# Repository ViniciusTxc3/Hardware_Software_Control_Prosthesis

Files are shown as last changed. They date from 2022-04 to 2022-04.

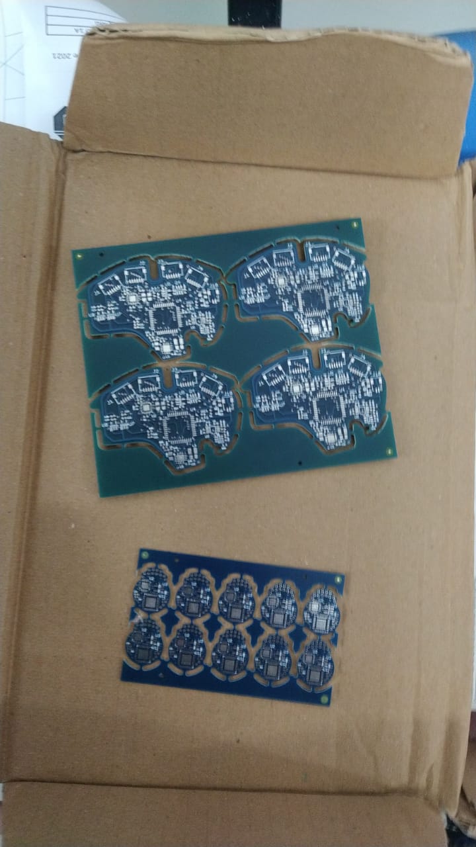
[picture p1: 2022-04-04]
img/placas_prontas.jpg

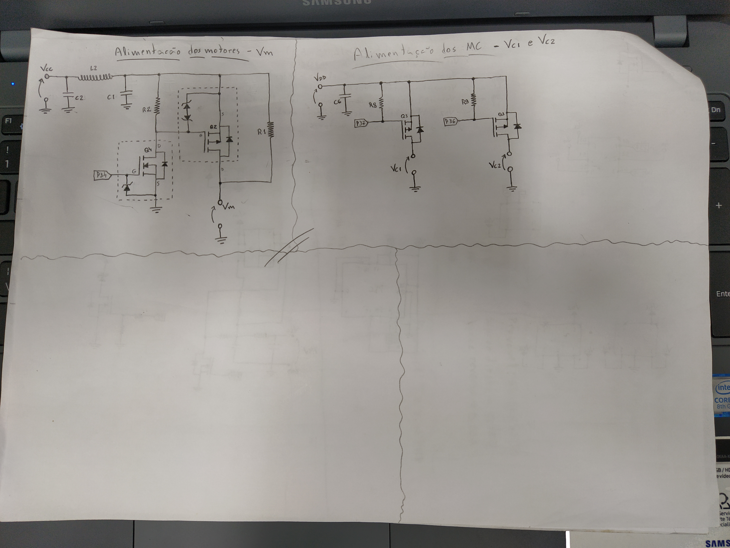
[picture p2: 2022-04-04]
img/rascunho/IMG_20200423_212037.jpg

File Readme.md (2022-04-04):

Trabalho desenvolvido no BioLab - UFU para o controle de uma prótese robótica. Nele consta o desenvolvimento do software de controle em um microcontrolador DSPIC em c/c++ e os design das placas de controle PCB.

# Esse trabalho teve a colaboração direta de:
* Vinicius Teixeira da Costa, 
* Professor Alcimar Barbosa Soares, 
* Eber Lawrence Gouveia, 
* Arthur Coeolho

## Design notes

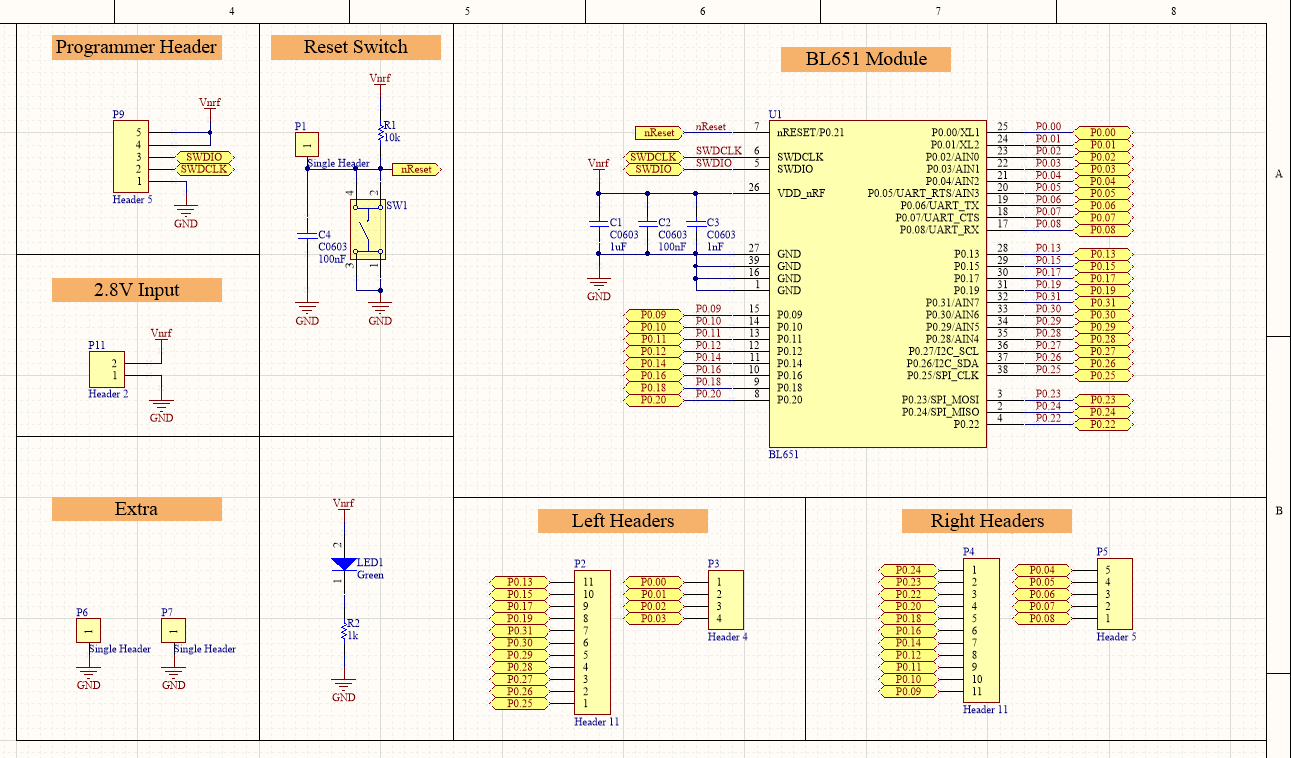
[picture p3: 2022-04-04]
datasheets/Bluetooth/Schematic_BL651.png

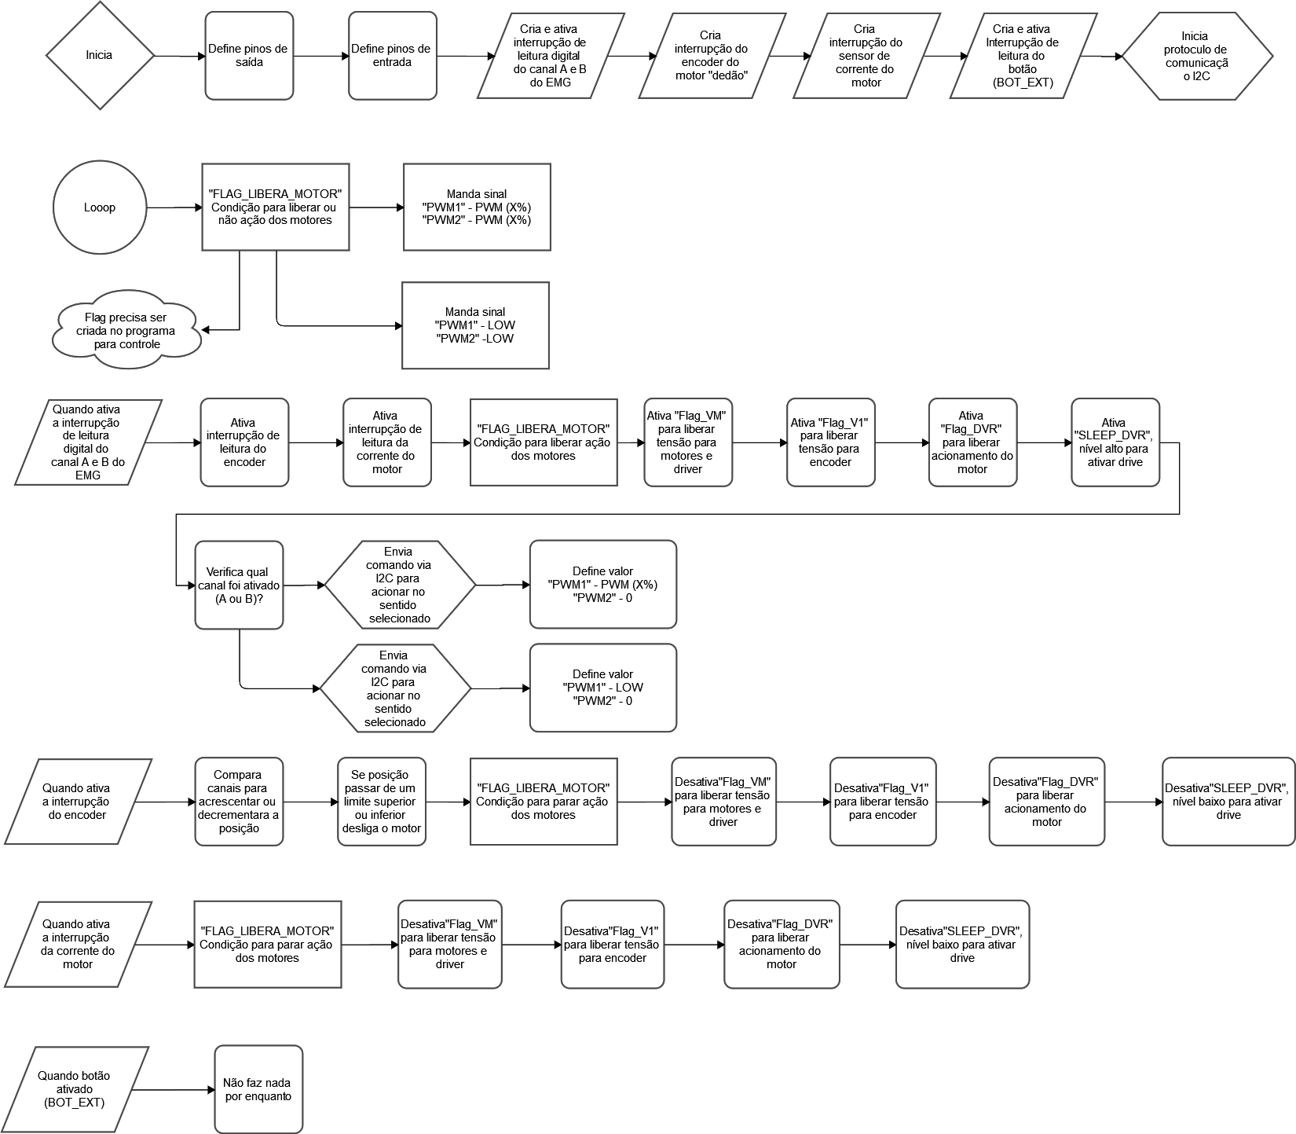
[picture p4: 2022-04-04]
Fluxograma_protese_grap_power.png

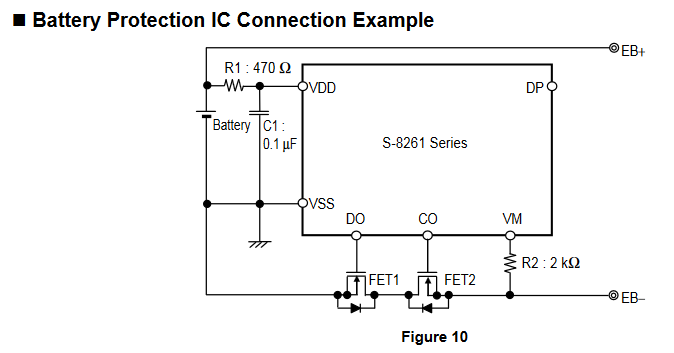
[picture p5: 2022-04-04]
datasheets/CIs/protection battery example.png

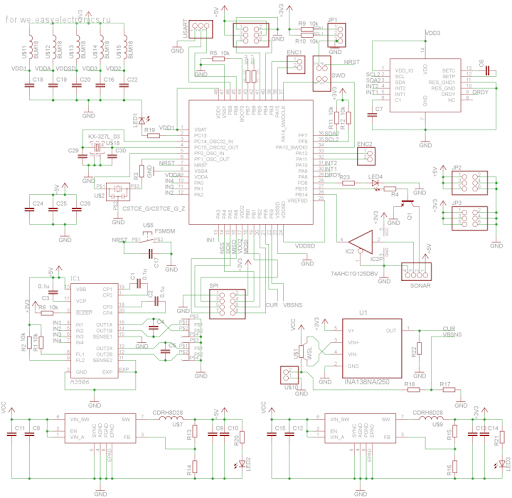
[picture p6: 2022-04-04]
datasheets/Driver potencia - A3906/example.png

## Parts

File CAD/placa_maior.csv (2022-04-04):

Qty | Value | Device | Package | Parts | Description | ALLIED_NUMBER | ALLIED_PRICE-STOCK | AVAILABILITY | DESCRIPTION | HEIGHT | MANUFACTURER_NAME | MANUFACTURER_PART_NUMBER | MF | MOUSER_PART_NUMBER | MOUSER_PRICE-STOCK | MP | MPN | OC_FARNELL | OC_NEWARK | PACKAGE | POPULARITY | PRICE | RS_PART_NUMBER | RS_PRICE-STOCK
1 | A3906SESTR-T | A3906 | QFN20 | U2 | Low Voltage Stepper and Single/Dual DC Motor Driver |  |  |  |  |  |  |  |  |  |  |  |  |  |  |  | 0
1 | 0.033R | R-US_R0805 | R0805 | R1 | RESISTOR, American symbol
13 | 0.1uF | C-EUC0402K | C0402K | C1, C2, C3, C4, C6, C8, C9, C11, C12, C14, C15, C21, C27 | CAPACITOR, European symbol
2 | 100K | R-US_R0402 | R0402 | R46, R58 | RESISTOR, American symbol
1 | 100R | R-US_R0402 | R0402 | R26 | RESISTOR, American symbol
2 | 10K | R-US_R0402 | R0402 | R42, R43 | RESISTOR, American symbol
13 | 10k | R-US_R0402 | R0402 | R6, R18, R27, R29, R30, R32, R33, R35, R44, R51, R54, R56, R57 | RESISTOR, American symbol
1 | 10pF | C-EUC0402K | C0402K | C5 | CAPACITOR, European symbol
1 | 10uF | C-EUC0402K | C0402K | C20 | CAPACITOR, European symbol
4 | 10uF | C-EUC0805K | C0805K | C7, C10, C16, C31 | CAPACITOR, European symbol
2 | 120R | R-US_R0402 | R0402 | R7, R15 | RESISTOR, American symbol
1 | 18k | R-US_R0402 | R0402 | R10 | RESISTOR, American symbol
1 | 190k | R-US_R0402 | R0402 | R5 | RESISTOR, American symbol
1 | 1M | R-US_R0402 | R0402 | R49 | RESISTOR, American symbol
3 | 1k | R-US_R0402 | R0402 | R3, R28, R37 | RESISTOR, American symbol
5 | 1uF | C-EUC0402K | C0402K | C13, C17, C25, C26, C32 | CAPACITOR, European symbol
2 | 2.2uF | C-EUC0402K | C0402K | C34, C35 | CAPACITOR, European symbol
1 | 22uF | C-EUC0805K | C0805K | C30 | CAPACITOR, European symbol
2 | 27k | R-US_R0402 | R0402 | R40, R41 | RESISTOR, American symbol
1 | 2k2 | R-US_R0402 | R0402 | R50 | RESISTOR, American symbol
1 | 39k | R-US_R0402 | R0402 | R55 | RESISTOR, American symbol
1 | 470R | R-US_R0402 | R0402 | R36 | RESISTOR, American symbol
2 | 470pF | C-EUC0402K | C0402K | C23, C24 | CAPACITOR, European symbol
6 | 4k7 | R-US_R0402 | R0402 | R2, R8, R9, R11, R14, R34 | RESISTOR, American symbol
3 | 501568-0207 | 501568-0207 | 5015680207 | J5, J6, J10 | Molex PICO-CLASP Series, Series Number 501568, 1mm Pitch 2 Way 2 Row Right Angle PCB Header, Solder Termination, 1A |  |  |  | Molex PICO-CLASP Series, Series Number 501568, 1mm Pitch 2 Way 2 Row Right Angle PCB Header, Solder Termination, 1A | 3.4mm | Molex | 501568-0207 |  | 538-501568-0207 | https://www.mouser.co.uk/ProductDetail/Molex/501568-0207?qs=uEWtSLL707WbFjnit2JOEg%3D%3D
1 | 501568-0407 | 501568-0407 | 501568-0407 | J8 | MOLEX - 501568-0407 - HEADER, 1.00MM, 4WAY | 70372951 | https://www.alliedelec.com/molex-incorporated-501568-0407/70372951/ |  | MOLEX - 501568-0407 - HEADER, 1.00MM, 4WAY | mm | Molex | 501568-0407 |  | 538-501568-0407 | https://www.mouser.co.uk/ProductDetail/Molex/501568-0407?qs=uEWtSLL707XxbhccfDRWNQ%3D%3D |  |  |  |  |  |  |  | 0406710P | http://uk.rs-online.com/web/p/products/0406710P
6 | 501568-0607 | 501568-0607 | 501568-0607 | J1, J2, J3, J4, J7, J9 | MOLEX - 501568-0607 - HEADER, 1.00MM, 6WAY | 70372952 | https://www.alliedelec.com/molex-incorporated-501568-0607/70372952/ |  | MOLEX - 501568-0607 - HEADER, 1.00MM, 6WAY | mm | Molex | 501568-0607 |  | 538-501568-0607 | https://www.mouser.co.uk/ProductDetail/Molex/501568-0607?qs=uEWtSLL707W5cp1jFOkIrg%3D%3D |  |  |  |  |  |  |  | 0406714P | http://uk.rs-online.com/web/p/products/0406714P
1 | 6.8uH | L-USL2825P | L2825P | L3 | INDUCTOR, American symbol
1 | 68uH | L-USL2825P | L2825P | L1 | INDUCTOR, American symbol
1 | ADUM1250 | ADUM1250 | SO8-COOL | U3 | Hot Swappable, Dual I2C Isolators |  |  | Unavailable | I²C Digital Isolator 2500Vrms 2 Channel 1Mbps 25kV/µs CMTI 8-SOIC _0.154, 3.90mm Width_ |  |  |  | Analog Devices |  |  | ADUM1250 |  |  |  | SOIC-8 Analog Devices |  | None
1 | ASDAIG-32.000MHZ-X-K-S-T | ASE | ASE | OSC1 | 3.3Vdc CMOS SMD CRYSTAL CLOCK OSCILLATOR |  |  |  |  |  |  |  |  |  |  |  |  | unknown | unknown
1 | BAT54HT1G | BAT54 | SOT23 | D2 | Schottky Diodes
1 | BL651 - 453-00005 | 453-00005 | 45300005 | U9 | Bluetooth Modules (802.15.1) BL651 Series - Bluetooth v5 Module, Int. Antenna (Nordic nRF52810) Tape & Reel |  |  |  | Bluetooth Modules (802.15.1) BL651 Series - Bluetooth v5 Module, Int. Antenna (Nordic nRF52810) Tape & Reel | 2.2mm | Laird Technologies | 453-00005 |  | 239-453-00005 | https://www.mouser.com/Search/Refine.aspx?Keyword=239-453-00005
2 | BZT52C3V3LP-7 | DIODE-MINIMELF | MINIMELF | D1, D3 | DIODE
1 | DMN2215UDM-7 | DMN2215UDM-7 | SOT95P285X140-6N | Q1 | Diodes Inc DMN2215UDM-7 Dual N-channel MOSFET Transistor, 2 A, 20 V, 6-Pin SOT-26 |  |  |  | Diodes Inc DMN2215UDM-7 Dual N-channel MOSFET Transistor, 2 A, 20 V, 6-Pin SOT-26 | 1.4mm | Diodes Inc. | DMN2215UDM-7 |  | 621-DMN2215UDM-7 | https://www.mouser.co.uk/ProductDetail/Diodes-Incorporated/DMN2215UDM-7?qs=ptj1V1atRArXZWZ7Y9ryoQ%3D%3D
2 | DMN2300U-7DICT-ND | DMN2300U-7 | SOT96P240X110-3N | Q2, Q3 | 20V N-Channel Enhancement MOSFET SOT-23 Diodes Inc DMN2300U-7 N-channel MOSFET Transistor, 1.4 A, 20 V, 3-Pin SOT-23 |  |  |  | 20V N-Channel Enhancement MOSFET SOT-23 Diodes Inc DMN2300U-7 N-channel MOSFET Transistor, 1.4 A, 20 V, 3-Pin SOT-23 | 1.1mm | Diodes Inc. | DMN2300U-7 |  | 621-DMN2300U-7 | https://www.mouser.co.uk/ProductDetail/Diodes-Incorporated/DMN2300U-7?qs=EumP11lMQtOINdAJqf8F6Q%3D%3D
1 | DMP2240UDM-7 | DMP2240UDM-7 | SOT95P285X140-6N | Q4 | Diodes Inc DMP2240UDM-7 Dual P-channel MOSFET Transistor, 2 A, -20 V, 6-Pin SOT-26 |  |  |  | Diodes Inc DMP2240UDM-7 Dual P-channel MOSFET Transistor, 2 A, -20 V, 6-Pin SOT-26 | 1.4mm | Diodes Inc. | DMP2240UDM-7 |  | 621-DMP2240UDM-7 | https://www.mouser.co.uk/ProductDetail/Diodes-Incorporated/DMP2240UDM-7?qs=mno522deGfakW12JLK9H1A%3D%3D
1 | DSPIC33FJ128MC804-I/PT | DSPIC33FJ128MC804-I/PT | QFP80P1200X1200X120-44N | U4 | Digital Signal Controllers |  |  | Unavailable | dsPIC dsPIC™ 33F Microcontroller IC 16-Bit 40 MIPs 128KB _128K x 8_ FLASH 44-TQFP _10x10_ |  |  |  | Microchip |  |  | DSPIC33FJ128MC804-I/PT |  |  |  | TQFP-44 Microchip |  | None
2 | FDS6675BZCT-ND | FDS6675BZ | SOIC127P600X175-8N | Q9, Q88 | FDS6675BZ, P-channel MOSFET Transistor 11A 30V, 8-Pin SOIC |  |  |  | FDS6675BZ, P-channel MOSFET Transistor 11A 30V, 8-Pin SOIC | 1.75mm | ON Semiconductor | FDS6675BZ |  | 512-FDS6675BZ | https://www.mouser.co.uk/ProductDetail/ON-Semiconductor-Fairchild/FDS6675BZ?qs=QGk6feVlqMIIlsKkGfvkgA%3D%3D
1 | MCP6002T-I_MS | MCP6002T-I_MS | SOP65P490X110-8N | U6 | MCP6002T-I/MS Microchip,, Op Amp, RRIO, 1MHz, 1.8 6 V, 8-Pin MSOP |  |  |  | MCP6002T-I/MS Microchip,, Op Amp, RRIO, 1MHz, 1.8 6 V, 8-Pin MSOP | 1.1mm | Microchip | MCP6002T-I/MS |  | 579-MCP6002T-I/MS | https://www.mouser.co.uk/ProductDetail/Microchip-Technology/MCP6002T-I-MS?qs=Q%2Fw7XRh99inDxHLK1Co8Rw%3D%3D
1 | MCP601T-I_OT | MCP601T-I_OT | SOT95P270X145-5N | U5 | 2.7 to 5.5V CMOS Operational Amplifier |  |  |  | 2.7 to 5.5V CMOS Operational Amplifier | 1.45mm | Microchip | MCP601T-I/OT |  | 579-MCP601T-I/OT | https://www.mouser.co.uk/ProductDetail/Microchip-Technology/MCP601T-I-OT?qs=TQnwojwsYvgI5ywjvKCAVw%3D%3D
2 | MIC5219-5.0YM5-TR | MIC5219-5.0YM5-TR | SOT95P280X145-5N | U7, U8 | LDO Voltage Regulators 500mA Peak 1% Low Noise LDO |  |  |  | LDO Voltage Regulators 500mA Peak 1% Low Noise LDO | 1.45mm | Microchip | MIC5219-5.0YM5-TR |  | 998-MIC5219-5.0YM5TR | https://www.mouser.co.uk/ProductDetail/Microchip-Technology-Micrel/MIC5219-50YM5-TR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
1 | NTK3134NT1GOSCT-ND | FDV303N | SOT23 | Q7 | Digital FET, N-Channel |  |  | Unavailable | FD V303N Series N-Channel 25 V 0.45 Ohm Surface Mount Digital FET - SOT-23-3 |  |  |  | Fairchild Semiconductor |  |  | FDV303N. |  |  |  | SOT-23-3 Fairchild Semiconductor |  | None
1 | PLZ9V1A-G3/H | DIODE-MINIMELF | MINIMELF | D33 | DIODE
1 | TPS62111RSAT | TPS62111RSAT | QFN65P400X400X100-17N | U1 | 3.3-V, 1.5-A, 17-V Vin Step-Down Converter in QFN-16 |  |  |  | 3.3-V, 1.5-A, 17-V Vin Step-Down Converter in QFN-16 | 1mm | Texas Instruments | TPS62111RSAT |  | 595-TPS62111RSAT | https://www.mouser.co.uk/ProductDetail/Texas-Instruments/TPS62111RSAT?qs=Gse6rAGbi7%2FXYp5rR0x3tg%3D%3D

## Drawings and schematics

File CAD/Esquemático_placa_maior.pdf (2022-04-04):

A

A

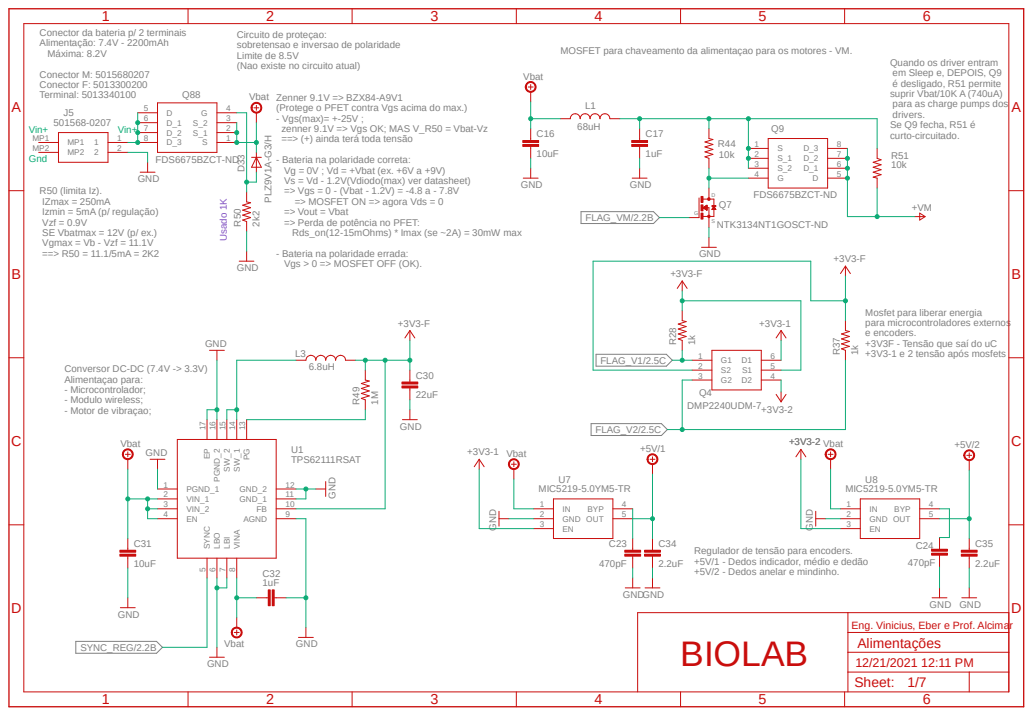
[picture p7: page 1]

Circuito de proteçao:
sobretensao e inversao de polaridade
Limite de 8.5V
(Nao existe no circuito atual)

MOSFET para chaveamento da alimentaçao para os motores - VM.

Quando os driver entram
em Sleep e, DEPOIS, Q9
é desligado, R51 permite
suprir Vbat/10K A (740uA)
para as charge pumps dos
drivers.
Se Q9 fecha, R51 é
curto-circuitado.

Vbat
Zenner 9.1V => BZX84-A9V1
(Protege o PFET contra Vgs acima do max.)
- Vgs(max)= +-25V ;
zenner 9.1V => Vgs OK; MAS V_R50 = Vbat-Vz
==> (+) ainda terá toda tensão
- Bateria na polaridade correta:
Vg = 0V ; Vd = +Vbat (ex. +6V a +9V)
Vs = Vd - 1.2V(Vdiodo(max) ver datasheet)
=> Vgs = 0 - (Vbat - 1.2V) = -4.8 a - 7.8V
=> MOSFET ON => agora Vds = 0
=> Vout = Vbat
=> Perda de potência no PFET:
Rds_on(12-15mOhms) * Imax (se ~2A) = 30mW max
- Bateria na polaridade errada:
Vgs > 0 => MOSFET OFF (OK).

Mosfet para liberar energia
para microcontroladores externos
e encoders.
+3V3F - Tensão que saí do uC
+3V3-1 e 2 tensão após mosfets

Regulador de tensão para encoders.
+5V/1 - Dedos indicador, médio e dedão
+5V/2 - Dedos anelar e mindinho.
BIOLAB

Eng. Vinicius, Eber e Prof. Alcimar
Alimentações
Sheet:

A

A

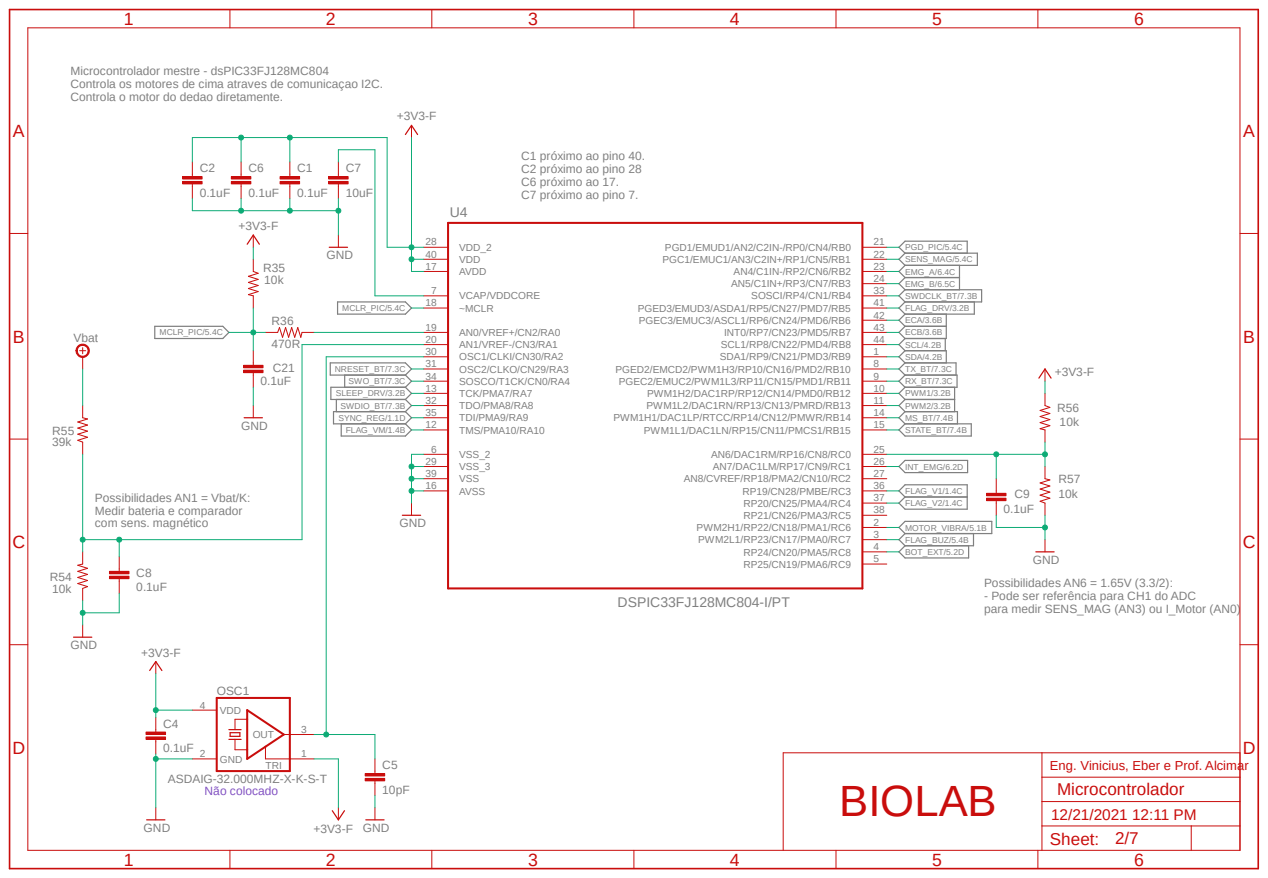
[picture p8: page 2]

Microcontrolador mestre - dsPIC33FJ128MC804
Controla os motores de cima atraves de comunicaçao I2C.
Controla o motor do dedao diretamente.

Possibilidades AN6 = 1.65V (3.3/2):
- Pode ser referência para CH1 do ADC
para medir SENS_MAG (AN3) ou I_Motor (AN0)

Eng. Vinicius, Eber e Prof. Alcimar
Microcontrolador
Sheet:

A

A

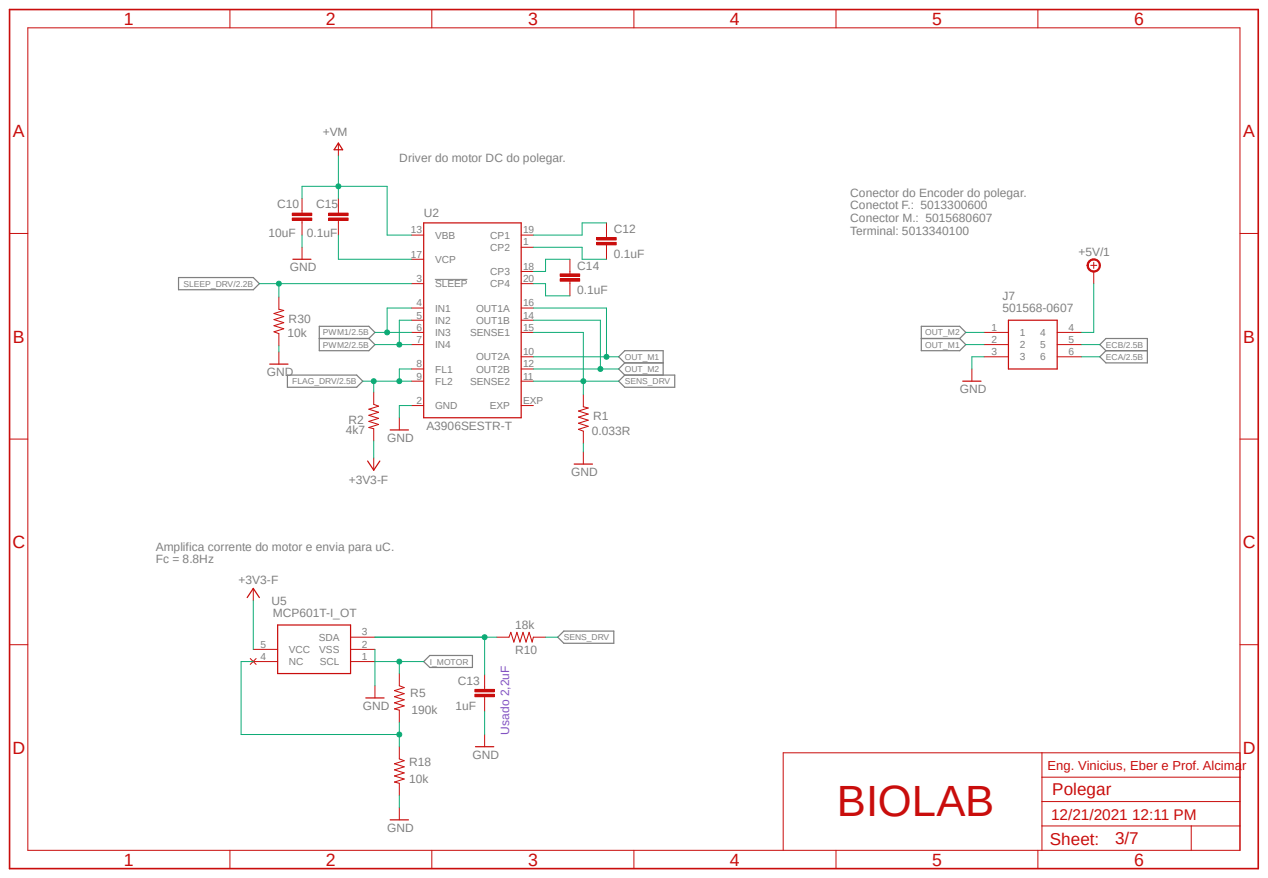
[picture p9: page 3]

Driver do motor DC do polegar.

Conector do Encoder do polegar.
Conectot F.: 5013300600
Conector M.: 5015680607
Terminal: 5013340100

Amplifica corrente do motor e envia para uC.

Eng. Vinicius, Eber e Prof. Alcimar
Polegar
Sheet:

A

A

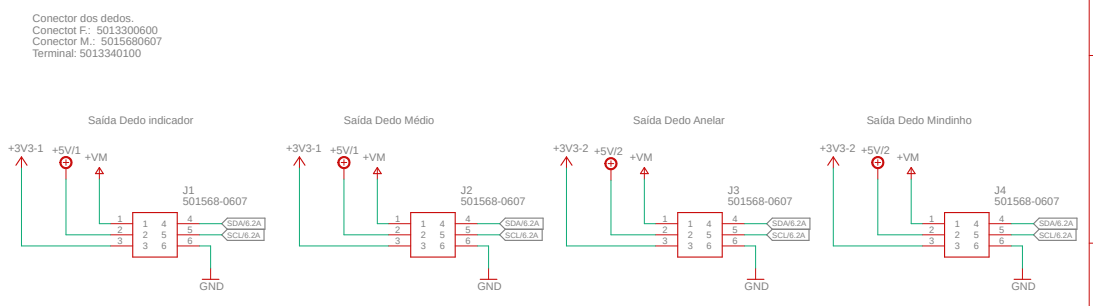
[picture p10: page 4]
Saída Dedo indicador; Saída Dedo Médio; Saída Dedo Anelar; Saída Dedo Mindinho; GND; SCL/6.2A; SDA/6.2A; BIOLAB

Conector dos dedos.
Conectot F.: 5013300600
Conector M.: 5015680607
Terminal: 5013340100

Eng. Vinicius, Eber e Prof. Alcimar
Demais dedos
Sheet:

A

A

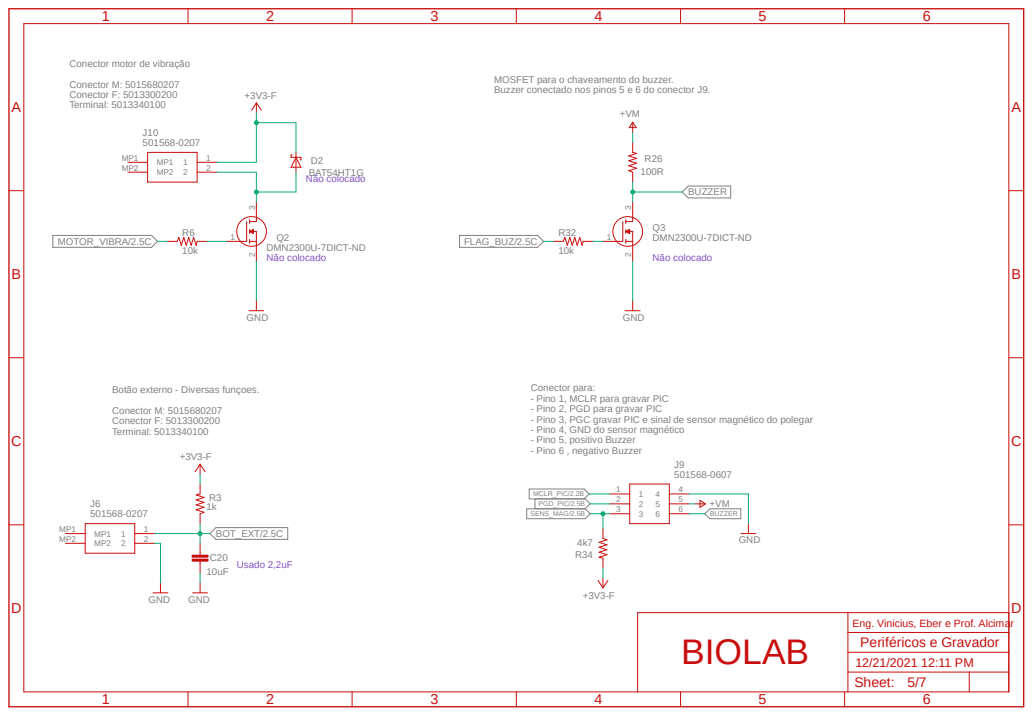
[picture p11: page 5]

MOSFET para o chaveamento do buzzer.
Buzzer conectado nos pinos 5 e 6 do conector J9.

Conector para:
- Pino 1, MCLR para gravar PIC
- Pino 2, PGD para gravar PIC
- Pino 3, PGC gravar PIC e sinal de sensor magnético do polegar
- Pino 4, GND do sensor magnético
- Pino 5, positivo Buzzer
- Pino 6 , negativo Buzzer

Eng. Vinicius, Eber e Prof. Alcimar
Periféricos e Gravador
Sheet:

A

A

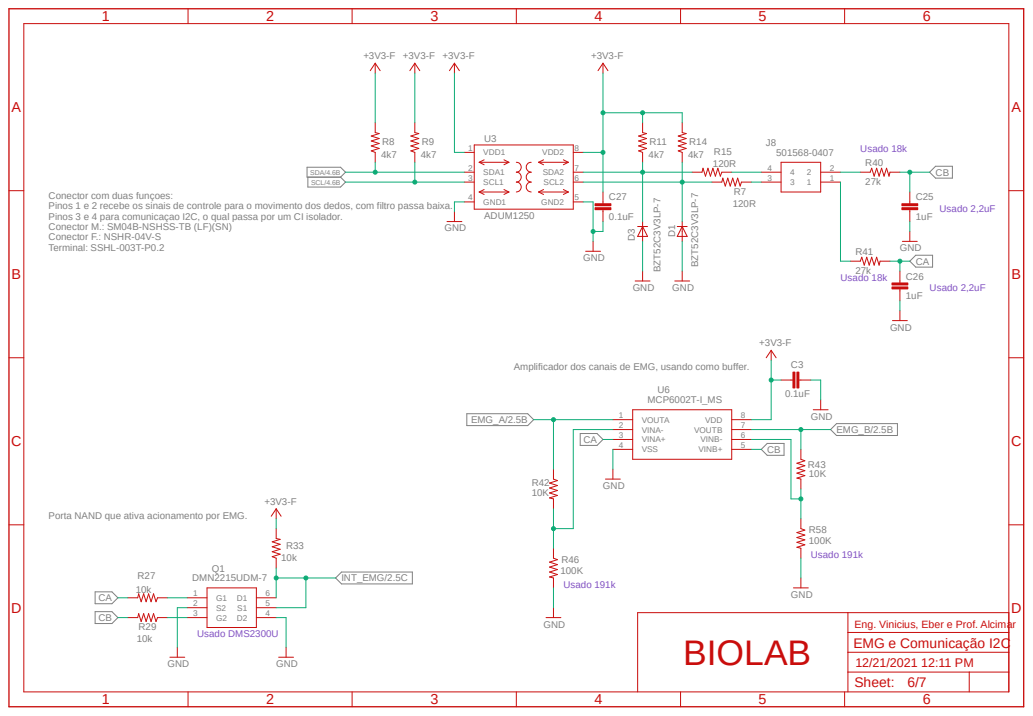
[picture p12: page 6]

Conector com duas funçoes:
Pinos 1 e 2 recebe os sinais de controle para o movimento dos dedos, com filtro passa baixa.
Pinos 3 e 4 para comunicaçao I2C, o qual passa por um CI isolador.
Conector M.: SM04B-NSHSS-TB (LF)(SN)
Conector F.: NSHR-04V-S
Terminal: SSHL-003T-P0.2

Amplificador dos canais de EMG, usando como buffer.

VINA+ 3
VSS 4 | CB

Porta NAND que ativa acionamento por EMG.

Eng. Vinicius, Eber e Prof. Alcimar
EMG e Comunicação I2C
Sheet:

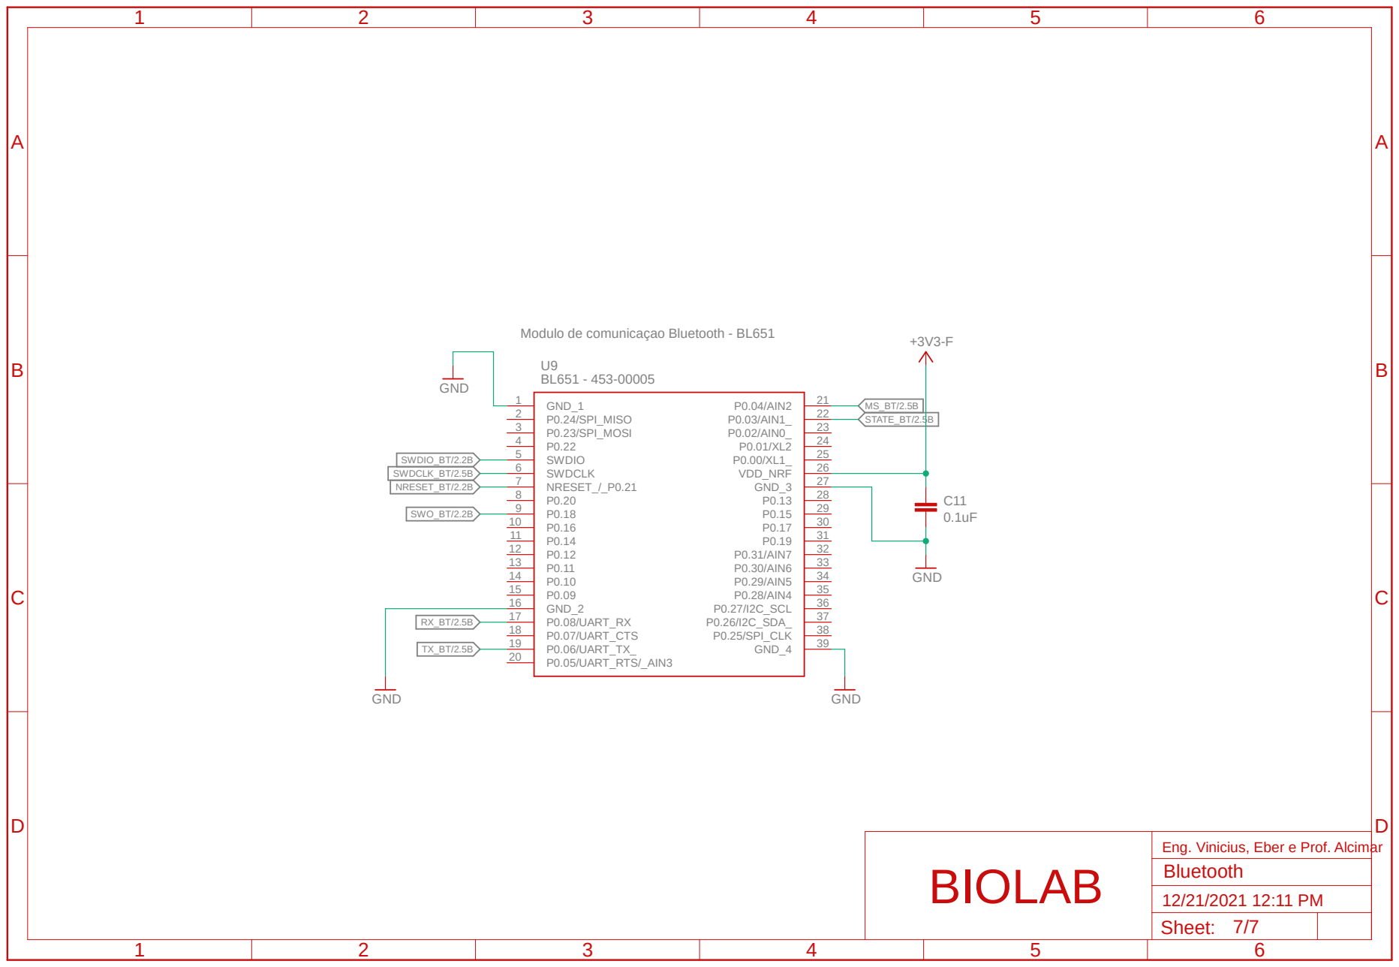
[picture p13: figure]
GND; GND_1 1 P0.24/SPI_MISO 2 P0.23/SPI_MOSI 3 P0.22 4 SWDIO 5 SWDCLK 6 NRESET_/_P0.21 7 P0.20 8 P0.18 9 P0.16 10 P0.14 11 P0.12 12 P0.11 13 P0.10 14 P0.09 15 GND_2 16 P0.08/UART_RX 17 P0.07/UART_CTS 18 P0.06/UART_TX_ 19 P0.05/UART_RTS/_AIN3 20; P0.04/AIN2; P0.03/AIN1_; P0.02/AIN0_; VDD_NRF; GND_3; P0.31/AIN7; P0.30/AIN6; P0.29/AIN5; P0.28/AIN4; P0.27/I2C_SCL; P0.26/I2C_SDA_; P0.25/SPI_CLK; GND_4; SWO_BT/2.2B; NRESET_BT/2.2B; SWDCLK_BT/2.5B; SWDIO_BT/2.2B; MS_BT/2.5B STATE_BT/2.5B; BIOLAB; Eng. Vinicius, Eber e Prof. Alcimar Bluetooth; Sheet:

Modulo de comunicaçao Bluetooth - BL651 | +3V3-F

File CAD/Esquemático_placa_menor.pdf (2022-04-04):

A

A

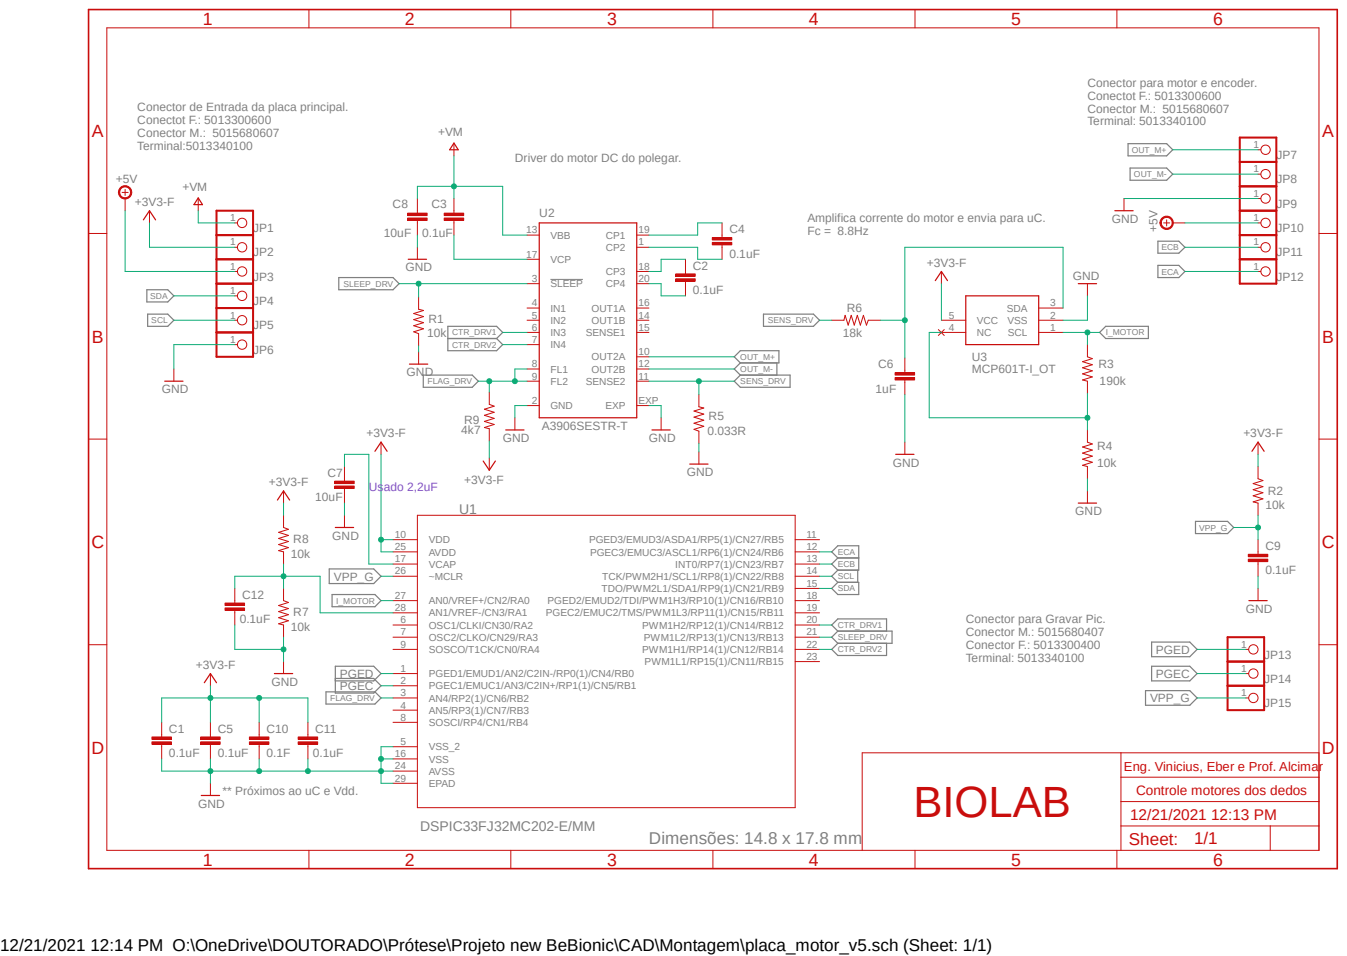
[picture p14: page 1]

Conector de Entrada da placa principal.
Conectot F.: 5013300600
Conector M.: 5015680607
Terminal:5013340100

Driver do motor DC do polegar.

Amplifica corrente do motor e envia para uC.

Eng. Vinicius, Eber e Prof. Alcimar
Controle motores dos dedos
Sheet:

** Próximos ao uC e Vdd.
GND

12/21/2021 12:14 PM O:\OneDrive\DOUTORADO\Prótese\Projeto new BeBionic\CAD\Montagem\placa_motor_v5.sch (Sheet: 1/1)

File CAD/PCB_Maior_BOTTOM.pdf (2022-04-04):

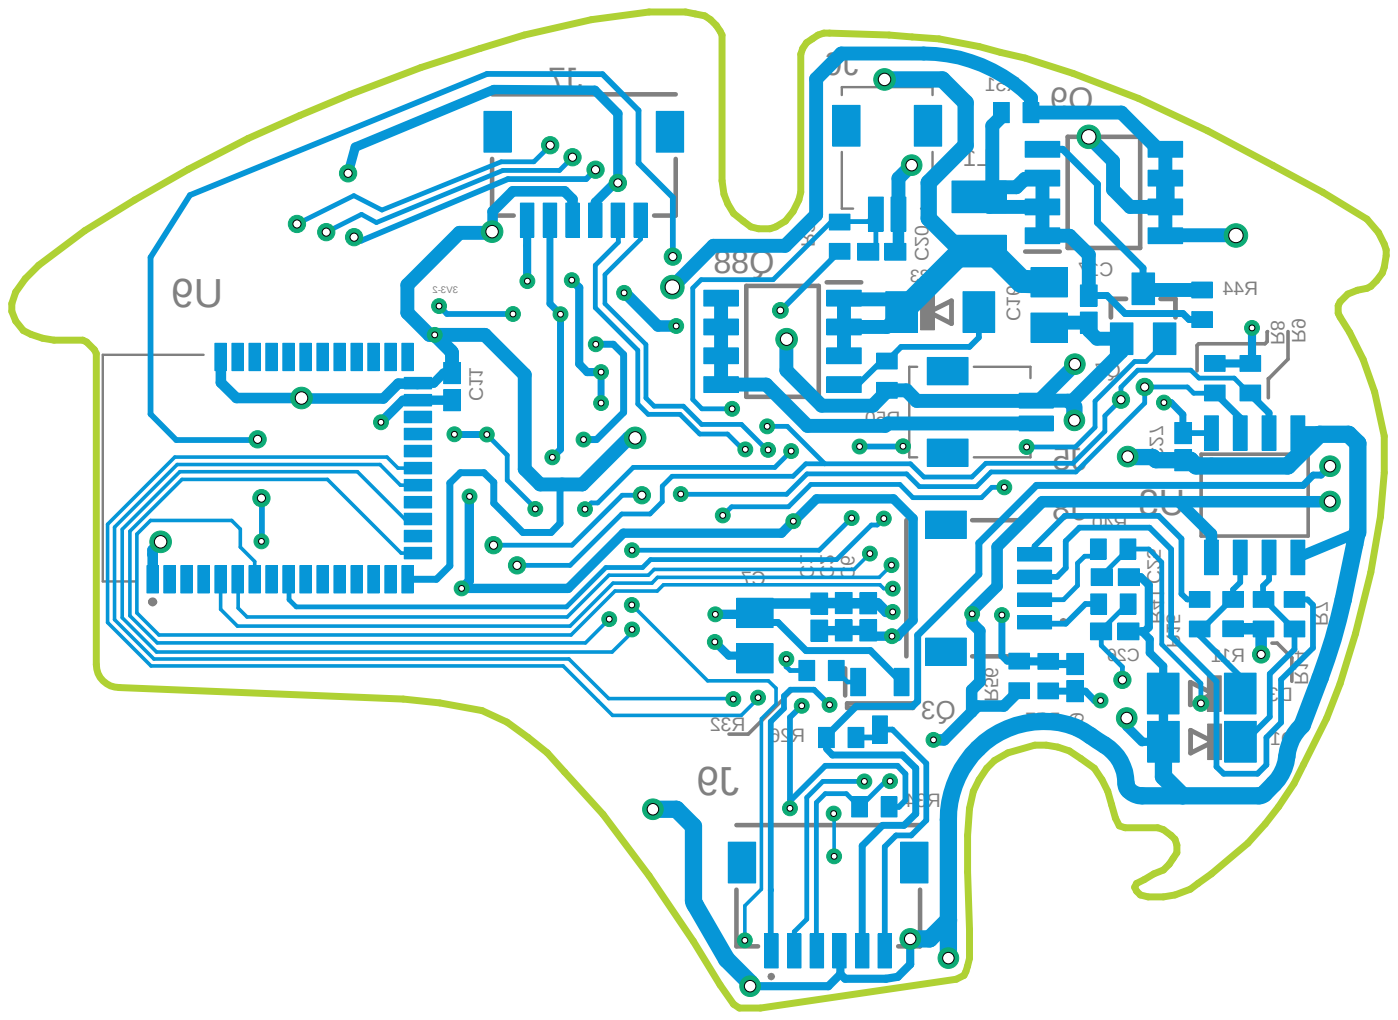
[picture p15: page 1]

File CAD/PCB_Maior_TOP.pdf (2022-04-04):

J2 J3

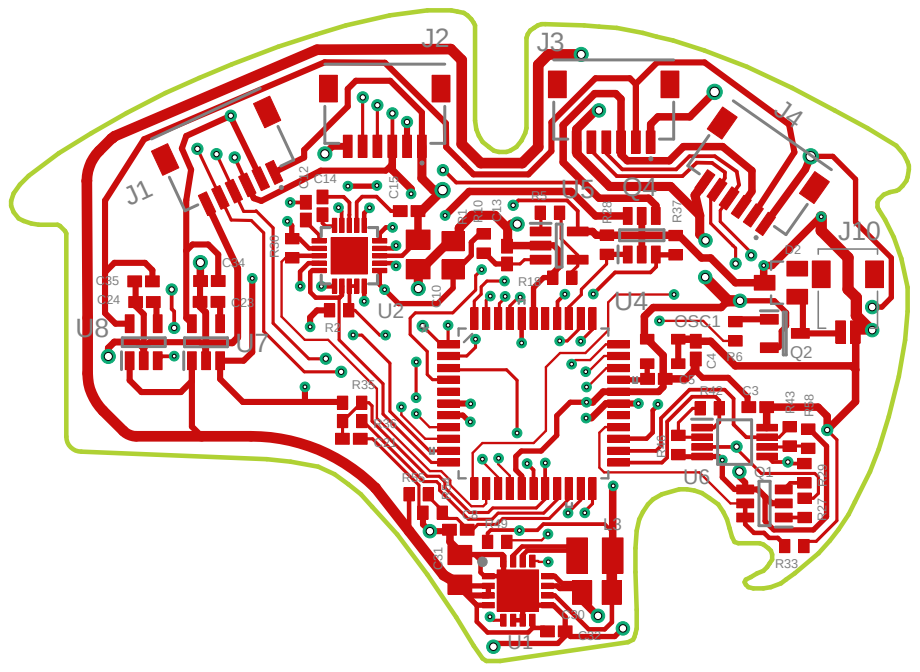
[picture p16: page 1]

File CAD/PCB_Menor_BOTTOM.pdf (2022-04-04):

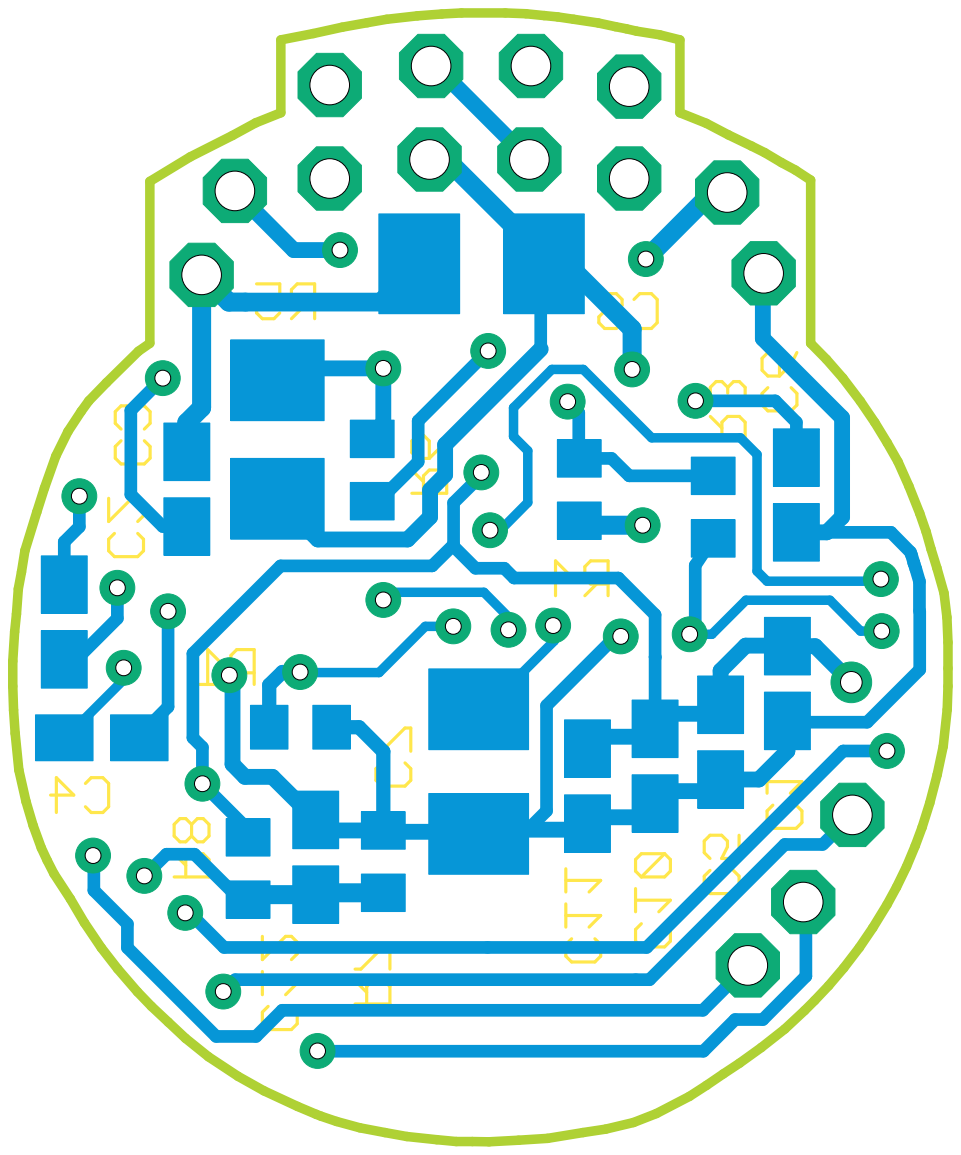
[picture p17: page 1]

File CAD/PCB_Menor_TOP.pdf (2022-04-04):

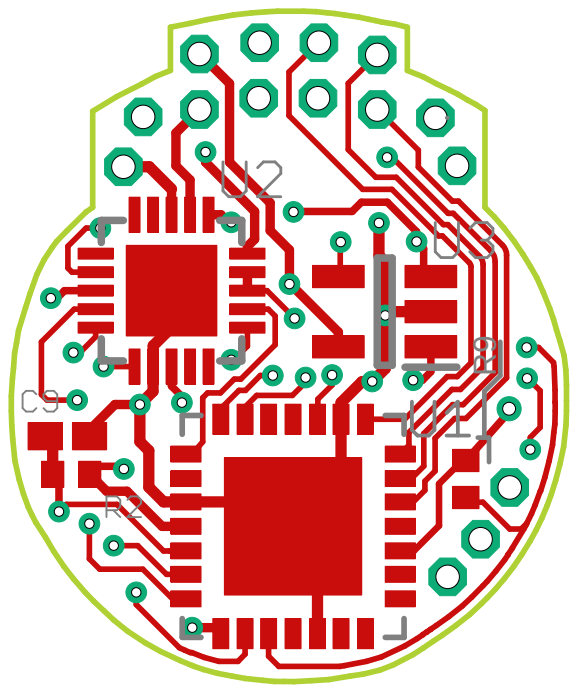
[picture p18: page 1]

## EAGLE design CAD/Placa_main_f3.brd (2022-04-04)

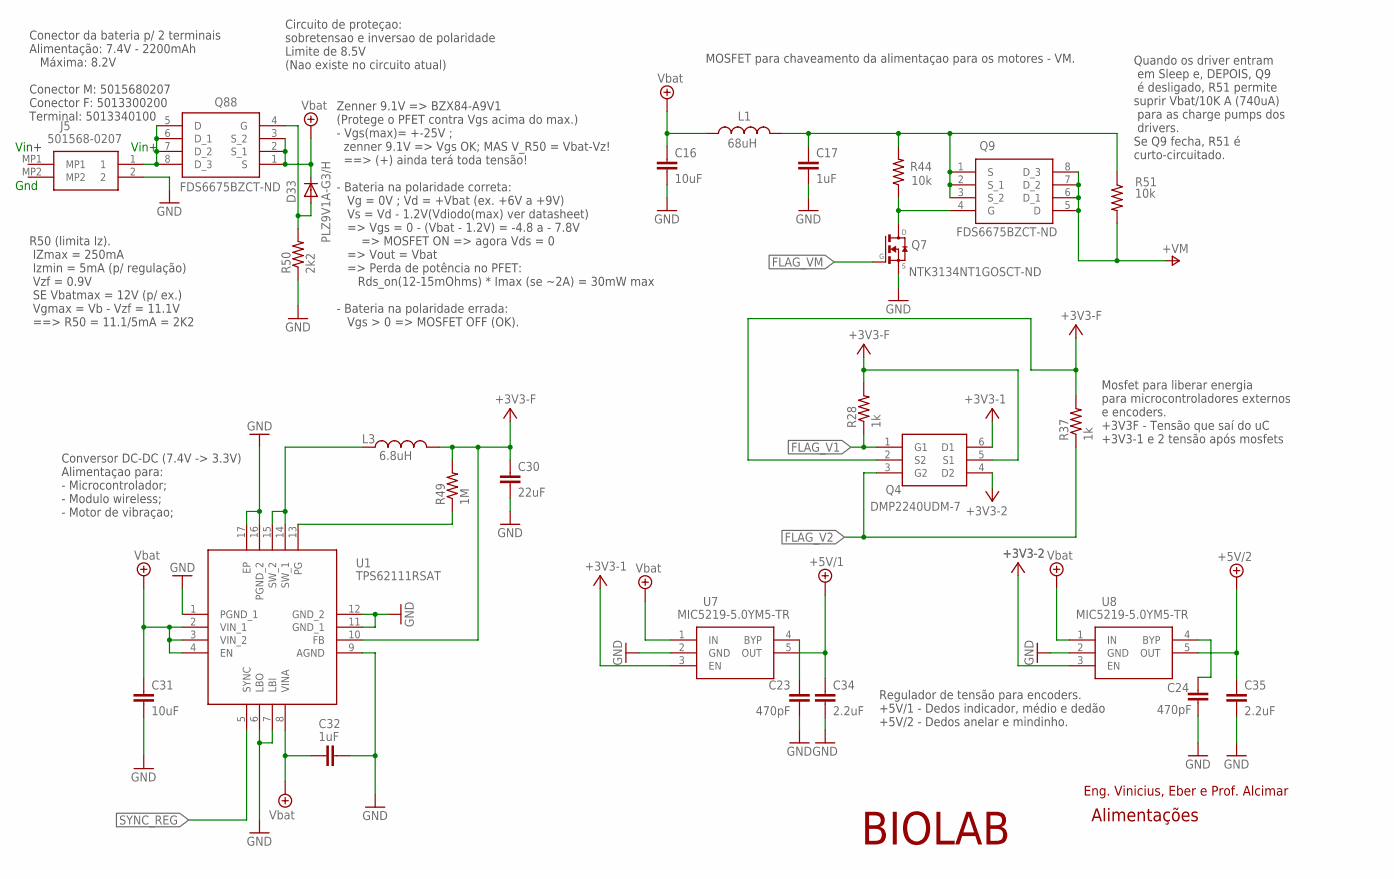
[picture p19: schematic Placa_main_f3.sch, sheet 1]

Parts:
C16, C31: 10uF; C0805K
C17, C32: 1uF; C0402K
C23, C24: 470pF; C0402K
C30: 22uF; C0805K
C34, C35: 2.2uF; C0402K
D33: PLZ9V1A-G3/H; MINIMELF
J5: 501568-0207; 5015680207
L1: 68uH; L2825P
L3: 6.8uH; L2825P
Q4: DMP2240UDM-7; SOT95P285X140-6N
Q7: NTK3134NT1GOSCT-ND; SOT23
Q9, Q88: FDS6675BZCT-ND; SOIC127P600X175-8N
R28, R37: 1k; R0402
R44, R51: 10k; R0402
R49: 1M; R0402
R50: 2k2; R0402
U1: TPS62111RSAT; QFN65P400X400X100-17N
U7, U8: MIC5219-5.0YM5-TR; SOT95P280X145-5N

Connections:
+3V3: C30.1, L3.2, Q4.2 (S2), Q4.5 (S1), R28.2, R37.2, R49.2, U1.10 (FB), U7.3 (EN); also elsewhere on the board
+3V3-1: Q4.6 (D1); also elsewhere on the board
+3V3-2: Q4.4 (D2), U8.3 (EN); also elsewhere on the board
+5V/1: C34.1, U7.5 (OUT); also elsewhere on the board
+5V/2: C35.1, U8.5 (OUT); also elsewhere on the board
FLAG_V1: Q4.1 (G1), R28.1; also elsewhere on the board
FLAG_V2: Q4.3 (G2), R37.1; also elsewhere on the board
FLAG_VM: Q7.1 (G); also elsewhere on the board
GND: C16.2, C17.2, C23.2, C24.2, C30.2, C31.2, C32.2, C34.2, C35.2, J5.2, Q7.2 (S), R50.1, U1.1 (PGND_1), U1.6 (LBO), U1.7 (LBI), U1.9 (AGND), U1.11 (GND_1), U1.12 (GND_2), U1.16 (PGND_2), U1.17 (EP), U7.2 (GND), U8.2 (GND); also elsewhere on the board
unnamed: C17.1, L1.2, Q9.1 (S), Q9.2 (S_1), Q9.3 (S_2), R44.2, R51.1
unnamed: Q7.3 (D), Q9.4 (G), R44.1
unnamed: C24.1, U8.4 (BYP)
unnamed: C23.1, U7.4 (BYP)
unnamed: R49.1, U1.13 (PG)
unnamed: L3.1, U1.14 (SW_1), U1.15 (SW_2)
unnamed: D33.A, Q88.4 (G), R50.2
SYNC_REG: U1.5 (SYNC); also elsewhere on the board
V+: Q9.5 (D), Q9.6 (D_1), Q9.7 (D_2), Q9.8 (D_3), R51.2; also elsewhere on the board
VBAT: C16.1, C31.1, C32.1, D33.C, L1.1, Q88.1 (S), Q88.2 (S_1), Q88.3 (S_2), U1.2 (VIN_1), U1.3 (VIN_2), U1.4 (EN), U1.8 (VINA), U7.1 (IN), U8.1 (IN); also elsewhere on the board
VIN+: J5.1, Q88.5 (D), Q88.6 (D_1), Q88.7 (D_2), Q88.8 (D_3)

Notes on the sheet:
Conector da bateria p/ 2 terminais Alimentação: 7.4V - 2200mAh Máxima: 8.2V Conector M: 5015680207 Conector F: 5013300200 Terminal: 5013340100
Circuito de proteçao: sobretensao e inversao de polaridade Limite de 8.5V (Nao existe no circuito atual)
Conversor DC-DC (7.4V -> 3.3V) Alimentaçao para: - Microcontrolador; - Modulo wireless; - Motor de vibraçao;
Regulador de tensão para encoders. +5V/1 - Dedos indicador, médio e dedão +5V/2 - Dedos anelar e mindinho.
MOSFET para chaveamento da alimentaçao para os motores - VM.
BIOLAB
Eng. Vinicius, Eber e Prof. Alcimar
Mosfet para liberar energia para microcontroladores externos e encoders. +3V3F - Tensão que saí do uC +3V3-1 e 2 tensão após mosfets
Alimentações
R50 (limita Iz). IZmax = 250mA Izmin = 5mA (p/ regulação) Vzf = 0.9V SE Vbatmax = 12V (p/ ex.) Vgmax = Vb - Vzf = 11.1V ==> R50 = 11.1/5mA = 2K2
Zenner 9.1V => BZX84-A9V1 (Protege o PFET contra Vgs acima do max.) - Vgs(max)= +-25V ; zenner 9.1V => Vgs OK; MAS V_R50 = Vbat-Vz! ==> (+) ainda terá toda tensão! - Bateria na polaridade correta: Vg = 0V ; Vd = +Vbat (ex. +6V a +9V) Vs = Vd - 1.2V(Vdiodo(max) ver datasheet) => Vgs = 0 - (Vbat - 1.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
Quando os driver entram em Sleep e, DEPOIS, Q9 é desligado, R51 permite suprir Vbat/10K A (740uA) para as charge pumps dos drivers. Se Q9 fecha, R51 é curto-circuitado.
Vin+
Gnd

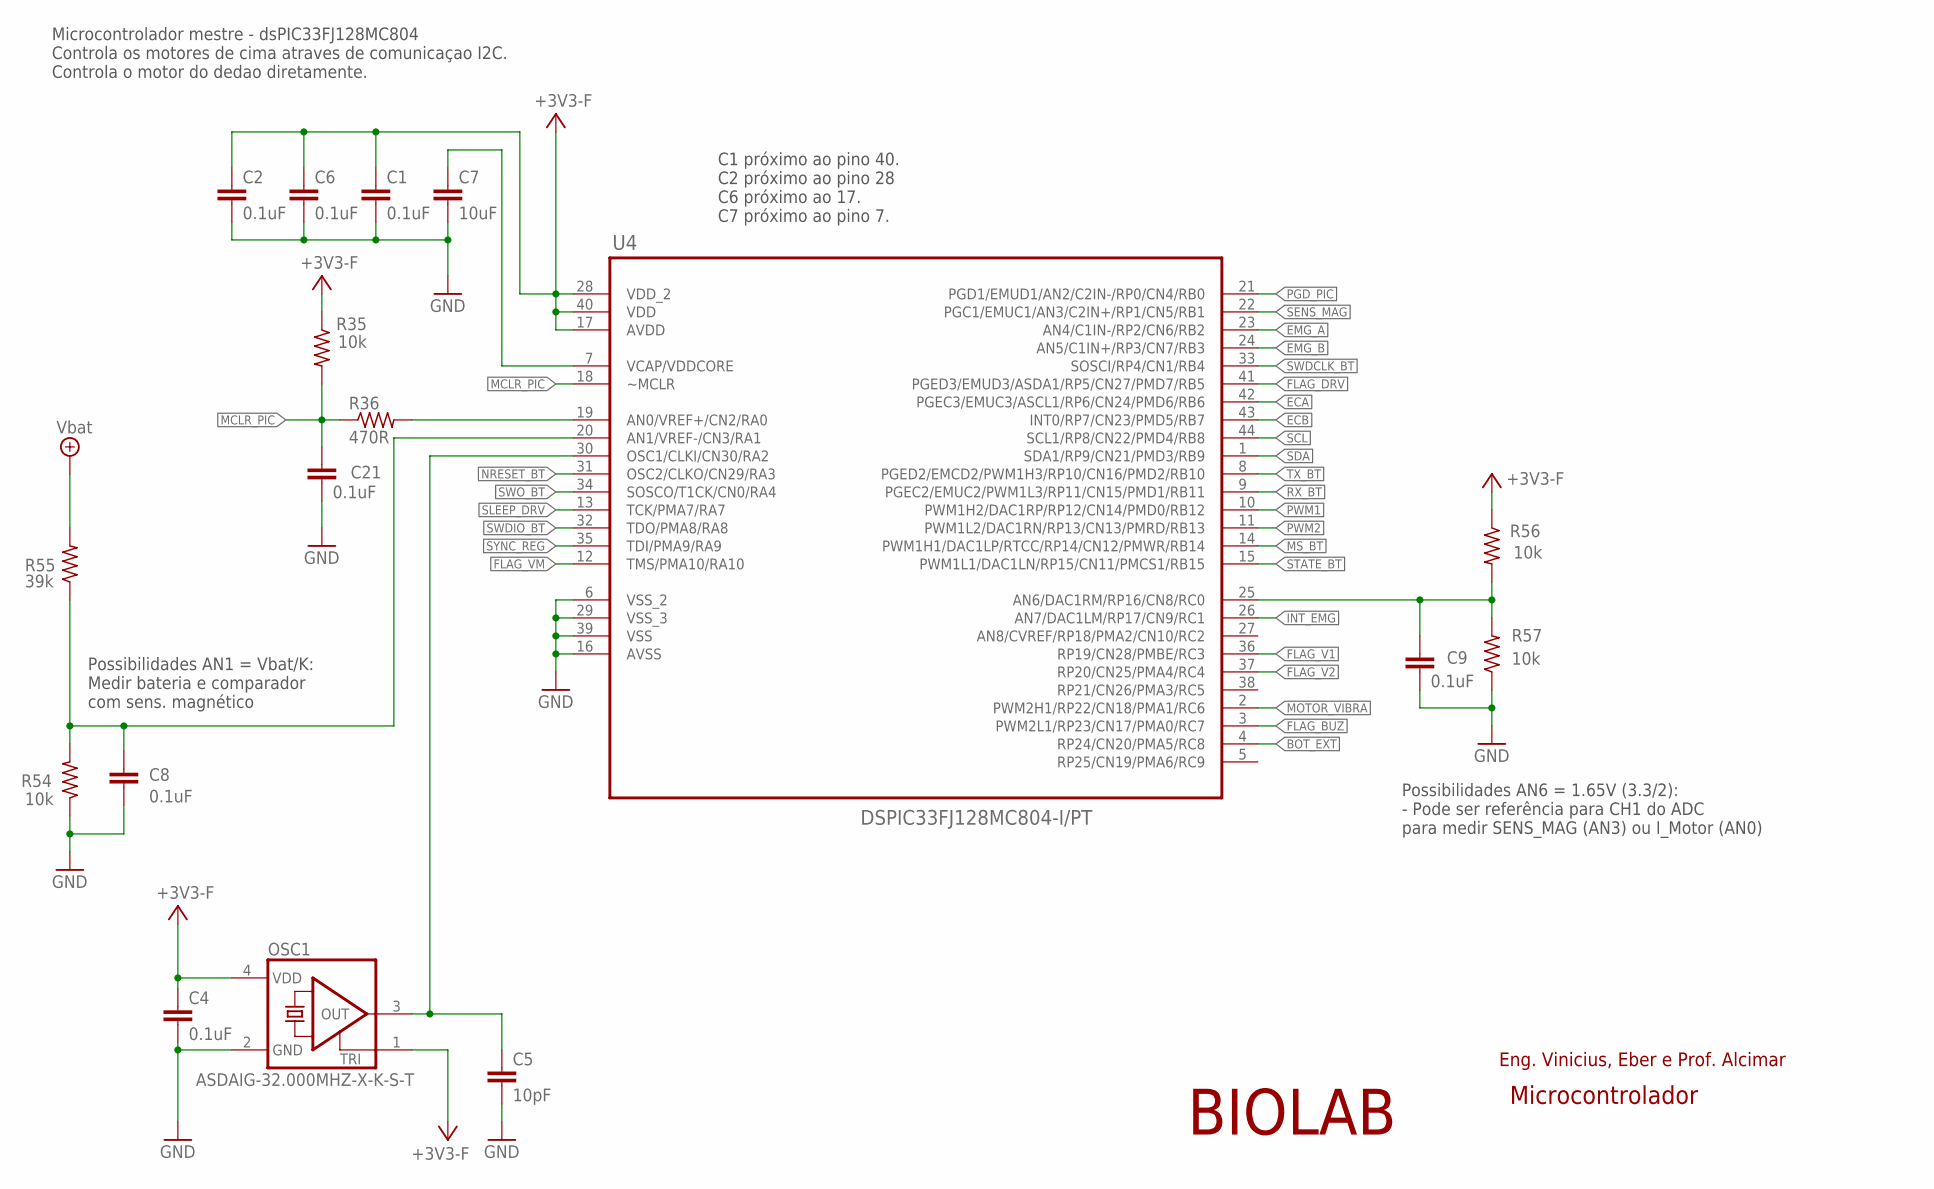
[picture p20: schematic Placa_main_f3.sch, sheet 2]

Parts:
C1, C2, C4, C6, C8, C9, C21: 0.1uF; C0402K
C5: 10pF; C0402K
C7: 10uF; C0805K
OSC1: ASDAIG-32.000MHZ-X-K-S-T; ASE
R35, R54, R56, R57: 10k; R0402
R36: 470R; R0402
R55: 39k; R0402
U4: DSPIC33FJ128MC804-I/PT; QFP80P1200X1200X120-44N

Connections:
+3V3: C1.1, C2.1, C4.1, C6.1, OSC1.1 (TRI), OSC1.4 (VDD), R35.1, R56.1, U4.17 (AVDD), U4.28 (VDD_2), U4.40 (VDD); also elsewhere on the board
BOT_EXT: U4.4 (RP24/CN20/PMA5/RC8); also elsewhere on the board
ECA: U4.42 (PGEC3/EMUC3/ASCL1/RP6/CN24/PMD6/RB6); also elsewhere on the board
ECB: U4.43 (INT0/RP7/CN23/PMD5/RB7); also elsewhere on the board
EMG_A: U4.23 (AN4/C1IN-/RP2/CN6/RB2); also elsewhere on the board
EMG_B: U4.24 (AN5/C1IN+/RP3/CN7/RB3); also elsewhere on the board
FLAG_BUZ: U4.3 (PWM2L1/RP23/CN17/PMA0/RC7); also elsewhere on the board
FLAG_DRV: U4.41 (PGED3/EMUD3/ASDA1/RP5/CN27/PMD7/RB5); also elsewhere on the board
FLAG_V1: U4.36 (RP19/CN28/PMBE/RC3); also elsewhere on the board
FLAG_V2: U4.37 (RP20/CN25/PMA4/RC4); also elsewhere on the board
FLAG_VM: U4.12 (TMS/PMA10/RA10); also elsewhere on the board
GND: C1.2, C2.2, C4.2, C5.2, C6.2, C7.2, C8.2, C9.2, C21.2, OSC1.2 (GND), R54.1, R57.1, U4.6 (VSS_2), U4.16 (AVSS), U4.29 (VSS_3), U4.39 (VSS); also elsewhere on the board
INT_EMG: U4.26 (AN7/DAC1LM/RP17/CN9/RC1); also elsewhere on the board
MCLR_PIC: C21.1, R35.2, R36.1, U4.18 (~MCLR); also elsewhere on the board
MOTOR_VIBRA: U4.2 (PWM2H1/RP22/CN18/PMA1/RC6); also elsewhere on the board
MS_BT: U4.14 (PWM1H1/DAC1LP/RTCC/RP14/CN12/PMWR/RB14); also elsewhere on the board
unnamed: C7.1, U4.7 (VCAP/VDDCORE)
unnamed: C9.1, R56.2, R57.2, U4.25 (AN6/DAC1RM/RP16/CN8/RC0)
unnamed: C8.1, R54.2, R55.1, U4.20 (AN1/VREF-/CN3/RA1)
unnamed: C5.1, OSC1.3 (OUT), U4.30 (OSC1/CLKI/CN30/RA2)
unnamed: R36.2, U4.19 (AN0/VREF+/CN2/RA0)
NRESET_BT: U4.31 (OSC2/CLKO/CN29/RA3); also elsewhere on the board
PGD_PIC: U4.21 (PGD1/EMUD1/AN2/C2IN-/RP0/CN4/RB0); also elsewhere on the board
PWM1: U4.10 (PWM1H2/DAC1RP/RP12/CN14/PMD0/RB12); also elsewhere on the board
PWM2: U4.11 (PWM1L2/DAC1RN/RP13/CN13/PMRD/RB13); also elsewhere on the board
RX_BT: U4.9 (PGEC2/EMUC2/PWM1L3/RP11/CN15/PMD1/RB11); also elsewhere on the board
SCL: U4.44 (SCL1/RP8/CN22/PMD4/RB8); also elsewhere on the board
SDA: U4.1 (SDA1/RP9/CN21/PMD3/RB9); also elsewhere on the board
SENS_MAG: U4.22 (PGC1/EMUC1/AN3/C2IN+/RP1/CN5/RB1); also elsewhere on the board
SLEEP_DRV: U4.13 (TCK/PMA7/RA7); also elsewhere on the board
STATE_BT: U4.15 (PWM1L1/DAC1LN/RP15/CN11/PMCS1/RB15); also elsewhere on the board
SWDCLK_BT: U4.33 (SOSCI/RP4/CN1/RB4); also elsewhere on the board
SWDIO_BT: U4.32 (TDO/PMA8/RA8); also elsewhere on the board
SWO_BT: U4.34 (SOSCO/T1CK/CN0/RA4); also elsewhere on the board
SYNC_REG: U4.35 (TDI/PMA9/RA9); also elsewhere on the board
TX_BT: U4.8 (PGED2/EMCD2/PWM1H3/RP10/CN16/PMD2/RB10); also elsewhere on the board
VBAT: R55.2; also elsewhere on the board

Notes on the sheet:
Microcontrolador mestre - dsPIC33FJ128MC804 Controla os motores de cima atraves de comunicaçao I2C. Controla o motor do dedao diretamente.
BIOLAB
Eng. Vinicius, Eber e Prof. Alcimar
Microcontrolador
C1 próximo ao pino 40. C2 próximo ao pino 28 C6 próximo ao 17. C7 próximo ao pino 7.
Possibilidades AN6 = 1.65V (3.3/2): - Pode ser referência para CH1 do ADC para medir SENS_MAG (AN3) ou I_Motor (AN0)
Possibilidades AN1 = Vbat/K: Medir bateria e comparador com sens. magnético

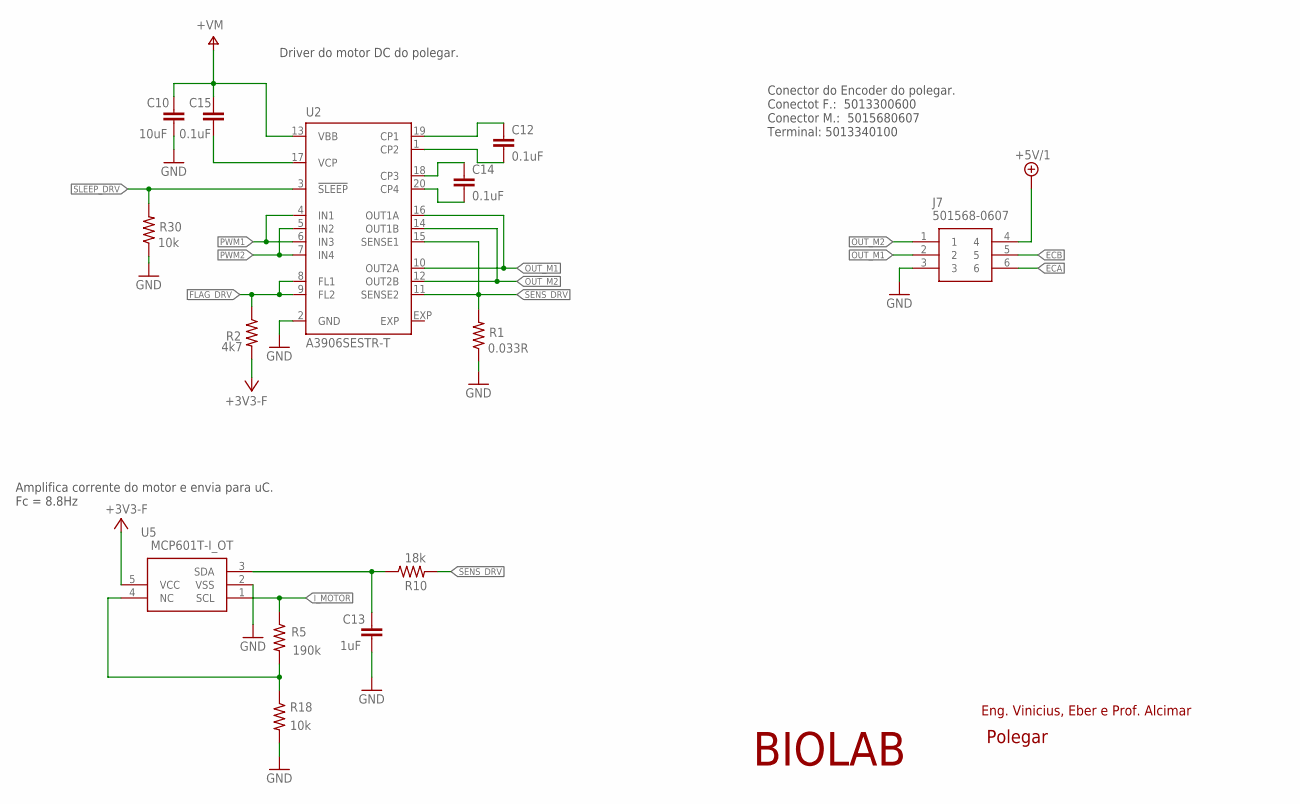
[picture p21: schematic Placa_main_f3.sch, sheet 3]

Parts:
C10: 10uF; C0805K
C12, C14, C15: 0.1uF; C0402K
C13: 1uF; C0402K
J7: 501568-0607
R1: 0.033R; R0805
R2: 4k7; R0402
R5: 190k; R0402
R10: 18k; R0402
R18, R30: 10k; R0402
U2: A3906SESTR-T; QFN20
U5: MCP601T-I_OT; SOT95P270X145-5N

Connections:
+3V3: R2.2, U5.5 (VCC); also elsewhere on the board
+5V/1: J7.4; also elsewhere on the board
ECA: J7.6; also elsewhere on the board
ECB: J7.5; also elsewhere on the board
FLAG_DRV: R2.1, U2.8 (FL1), U2.9 (FL2); also elsewhere on the board
GND: C10.1, C13.2, J7.3, R1.1, R18.2, R30.1, U2.2 (GND), U5.2 (VSS); also elsewhere on the board
I_MOTOR: R5.1, U5.1 (SCL)
unnamed: C13.1, R10.1, U5.3 (SDA)
unnamed: C12.2, U2.1 (CP2)
unnamed: C14.1, U2.18 (CP3)
unnamed: C15.2, U2.17 (VCP)
unnamed: C14.2, U2.20 (CP4)
unnamed: C12.1, U2.19 (CP1)
unnamed: R5.2, R18.1, U5.4 (NC)
OUT_M1: J7.2, U2.10 (OUT2A), U2.16 (OUT1A)
OUT_M2: J7.1, U2.12 (OUT2B), U2.14 (OUT1B)
PWM1: U2.4 (IN1), U2.6 (IN3); also elsewhere on the board
PWM2: U2.5 (IN2), U2.7 (IN4); also elsewhere on the board
SENS_DRV: R1.2, R10.2, U2.11 (SENSE2), U2.15 (SENSE1)
SLEEP_DRV: R30.2, U2.3 (!SLEEP); also elsewhere on the board
V+: C10.2, C15.1, U2.13 (VBB); also elsewhere on the board

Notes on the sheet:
Driver do motor DC do polegar.
Conector do Encoder do polegar. Conectot F.: 5013300600 Conector M.: 5015680607 Terminal: 5013340100
Amplifica corrente do motor e envia para uC. Fc = 8.8Hz
BIOLAB
Eng. Vinicius, Eber e Prof. Alcimar
Polegar

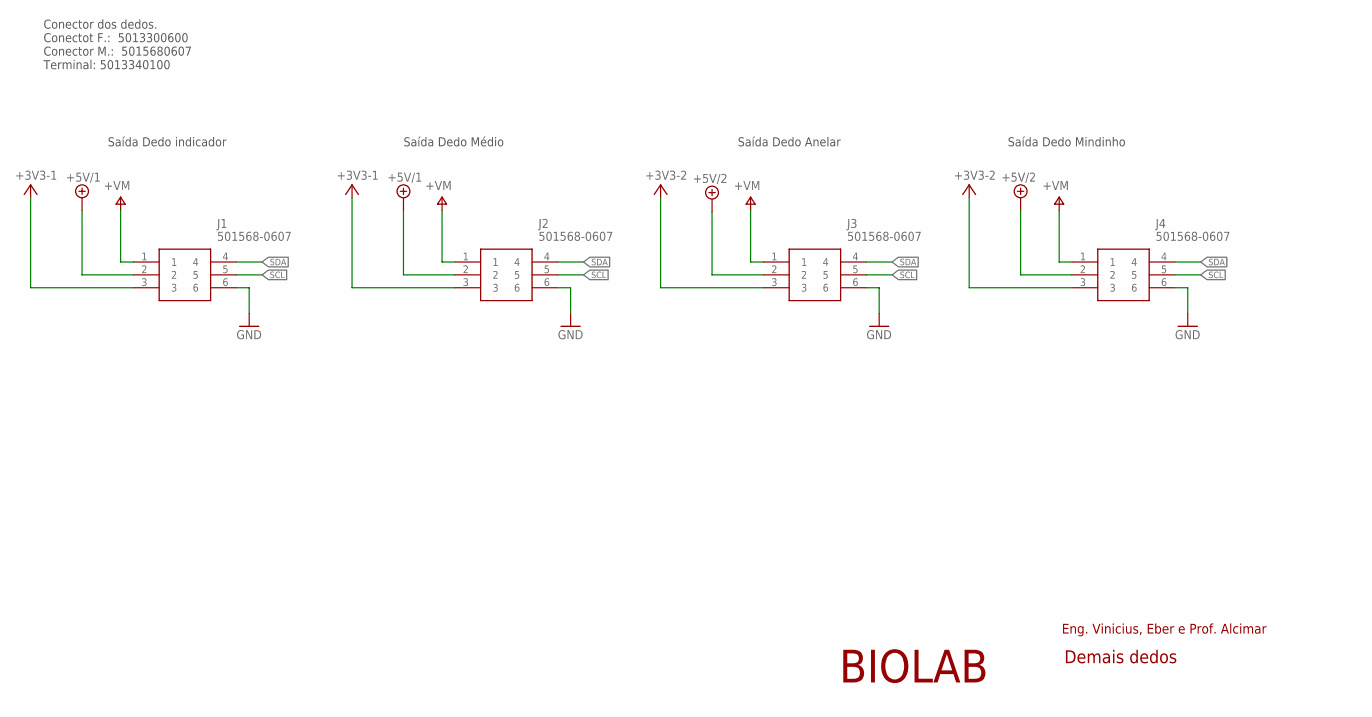
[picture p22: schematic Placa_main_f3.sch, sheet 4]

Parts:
J1, J2, J3, J4: 501568-0607

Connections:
+3V3-1: J1.3, J2.3; also elsewhere on the board
+3V3-2: J3.3, J4.3; also elsewhere on the board
+5V/1: J1.2, J2.2; also elsewhere on the board
+5V/2: J3.2, J4.2; also elsewhere on the board
GND: J1.6, J2.6, J3.6, J4.6; also elsewhere on the board
SCL: J1.5, J2.5, J3.5, J4.5; also elsewhere on the board
SDA: J1.4, J2.4, J3.4, J4.4; also elsewhere on the board
V+: J1.1, J2.1, J3.1, J4.1; also elsewhere on the board

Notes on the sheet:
BIOLAB
Eng. Vinicius, Eber e Prof. Alcimar
Demais dedos
Conector dos dedos. Conectot F.: 5013300600 Conector M.: 5015680607 Terminal: 5013340100
Saída Dedo indicador
Saída Dedo Médio
Saída Dedo Anelar
Saída Dedo Mindinho

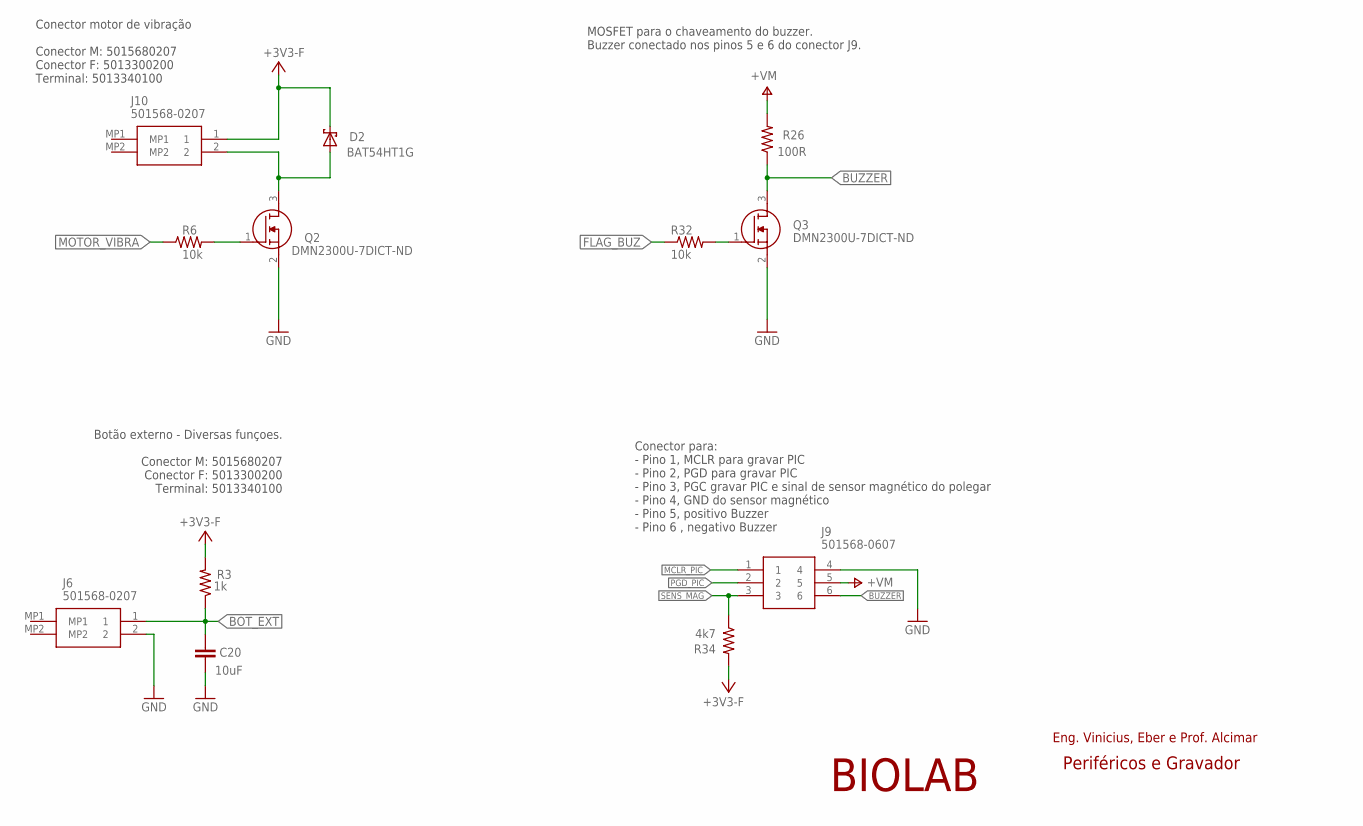
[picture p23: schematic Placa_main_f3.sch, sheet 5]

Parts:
C20: 10uF; C0402K
D2: BAT54HT1G; SOT23
J6, J10: 501568-0207; 5015680207
J9: 501568-0607
Q2, Q3: DMN2300U-7DICT-ND; SOT96P240X110-3N
R3: 1k; R0402
R6, R32: 10k; R0402
R26: 100R; R0402
R34: 4k7; R0402

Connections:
+3V3: D2.3 (C), J10.1, R3.2, R34.2; also elsewhere on the board
BOT_EXT: C20.1, J6.1, R3.1; also elsewhere on the board
BUZZER: J9.6, Q3.3 (D), R26.1
FLAG_BUZ: R32.1; also elsewhere on the board
GND: C20.2, J6.2, J9.4, Q2.2 (S), Q3.2 (S); also elsewhere on the board
MCLR_PIC: J9.1; also elsewhere on the board
MOTOR_VIBRA: R6.1; also elsewhere on the board
unnamed: Q2.1 (G), R6.2
unnamed: D2.1 (A), J10.2, Q2.3 (D)
unnamed: Q3.1 (G), R32.2
PGD_PIC: J9.2; also elsewhere on the board
SENS_MAG: J9.3, R34.1; also elsewhere on the board
V+: J9.5, R26.2; also elsewhere on the board

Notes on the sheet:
Botão externo - Diversas funçoes. Conector M: 5015680207 Conector F: 5013300200 Terminal: 5013340100
Conector para: - Pino 1, MCLR para gravar PIC - Pino 2, PGD para gravar PIC - Pino 3, PGC gravar PIC e sinal de sensor magnético do polegar - Pino 4, GND do sensor magnético - Pino 5, positivo Buzzer - Pino 6 , negativo Buzzer
MOSFET para o chaveamento do buzzer. Buzzer conectado nos pinos 5 e 6 do conector J9.
BIOLAB
Eng. Vinicius, Eber e Prof. Alcimar
Periféricos e Gravador
Conector motor de vibração Conector M: 5015680207 Conector F: 5013300200 Terminal: 5013340100

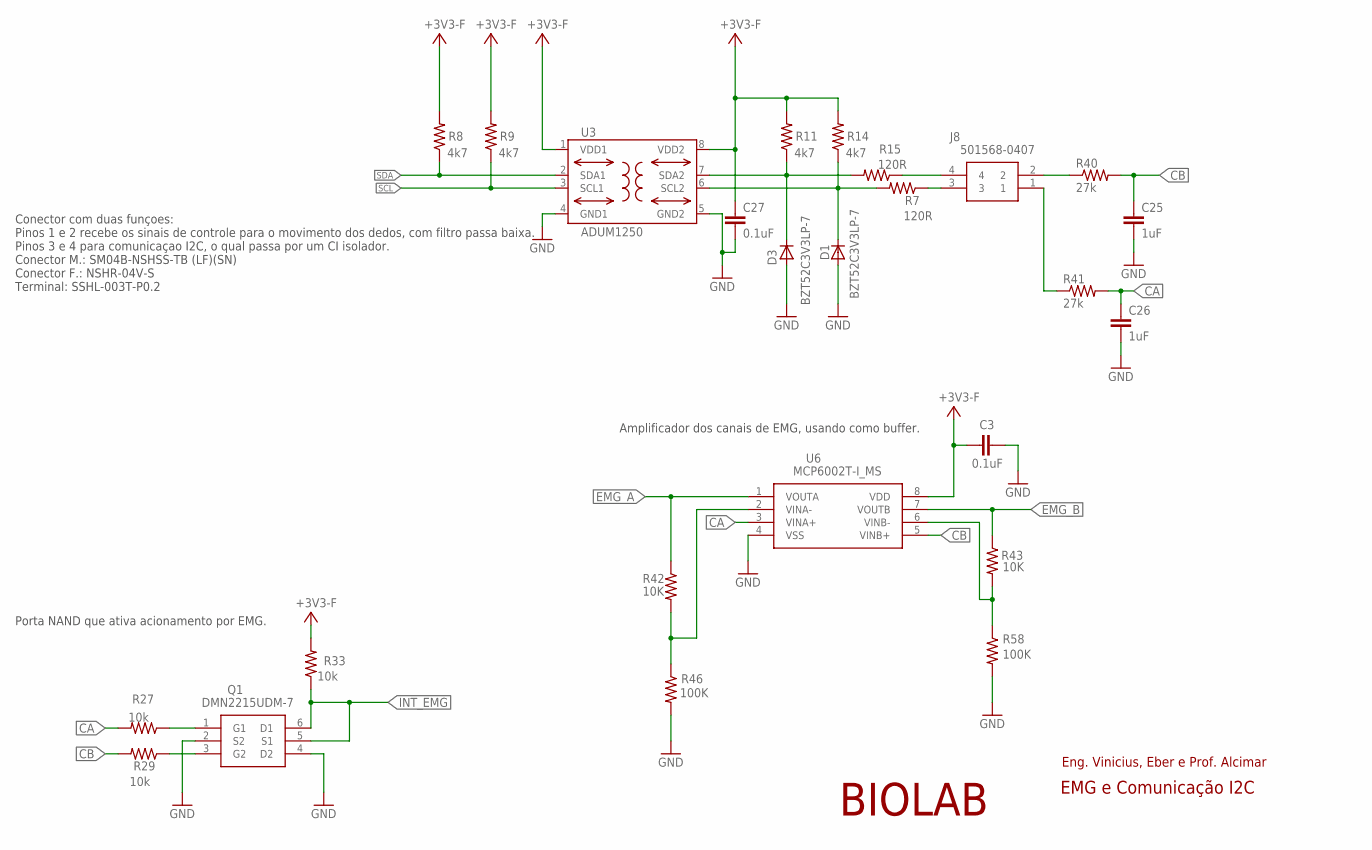
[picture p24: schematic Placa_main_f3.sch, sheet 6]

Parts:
C3, C27: 0.1uF; C0402K
C25, C26: 1uF; C0402K
D1, D3: BZT52C3V3LP-7; MINIMELF
J8: 501568-0407
Q1: DMN2215UDM-7; SOT95P285X140-6N
R7, R15: 120R; R0402
R8, R9, R11, R14: 4k7; R0402
R27, R29, R33: 10k; R0402
R40, R41: 27k; R0402
R42, R43: 10K; R0402
R46, R58: 100K; R0402
U3: ADUM1250; SO8-COOL
U6: MCP6002T-I_MS; SOP65P490X110-8N

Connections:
+3V3: C3.1, C27.1, R8.2, R9.2, R11.2, R14.2, R33.2, U3.1 (VDD1), U3.8 (VDD2), U6.8 (VDD); also elsewhere on the board
CA: C26.1, R27.2, R41.2, U6.3 (VINA+)
CB: C25.1, R29.2, R40.2, U6.5 (VINB+)
EMG_A: R42.1, U6.1 (VOUTA); also elsewhere on the board
EMG_B: R43.1, U6.7 (VOUTB); also elsewhere on the board
GND: C3.2, C25.2, C26.2, C27.2, D1.A, D3.A, Q1.2 (S2), Q1.4 (D2), R46.2, R58.2, U3.4 (GND1), U3.5 (GND2), U6.4 (VSS); also elsewhere on the board
INT_EMG: Q1.5 (S1), Q1.6 (D1), R33.1; also elsewhere on the board
unnamed: J8.3, R7.1
unnamed: D3.C, R11.1, R15.2, U3.7 (SDA2)
unnamed: Q1.1 (G1), R27.1
unnamed: Q1.3 (G2), R29.1
unnamed: J8.4, R15.1
unnamed: R42.2, R46.1, U6.2 (VINA-)
unnamed: R43.2, R58.1, U6.6 (VINB-)
unnamed: D1.C, R7.2, R14.1, U3.6 (SCL2)
unnamed: J8.2, R40.1
unnamed: J8.1, R41.1
SCL: R9.1, U3.3 (SCL1); also elsewhere on the board
SDA: R8.1, U3.2 (SDA1); also elsewhere on the board

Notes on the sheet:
BIOLAB
Eng. Vinicius, Eber e Prof. Alcimar
Conector com duas funçoes: Pinos 1 e 2 recebe os sinais de controle para o movimento dos dedos, com filtro passa baixa. Pinos 3 e 4 para comunicaçao I2C, o qual passa por um CI isolador. Conector M.: SM04B-NSHSS-TB (LF)(SN) Conector F.: NSHR-04V-S Terminal: SSHL-003T-P0.2
EMG e Comunicação I2C
Porta NAND que ativa acionamento por EMG.
Amplificador dos canais de EMG, usando como buffer.

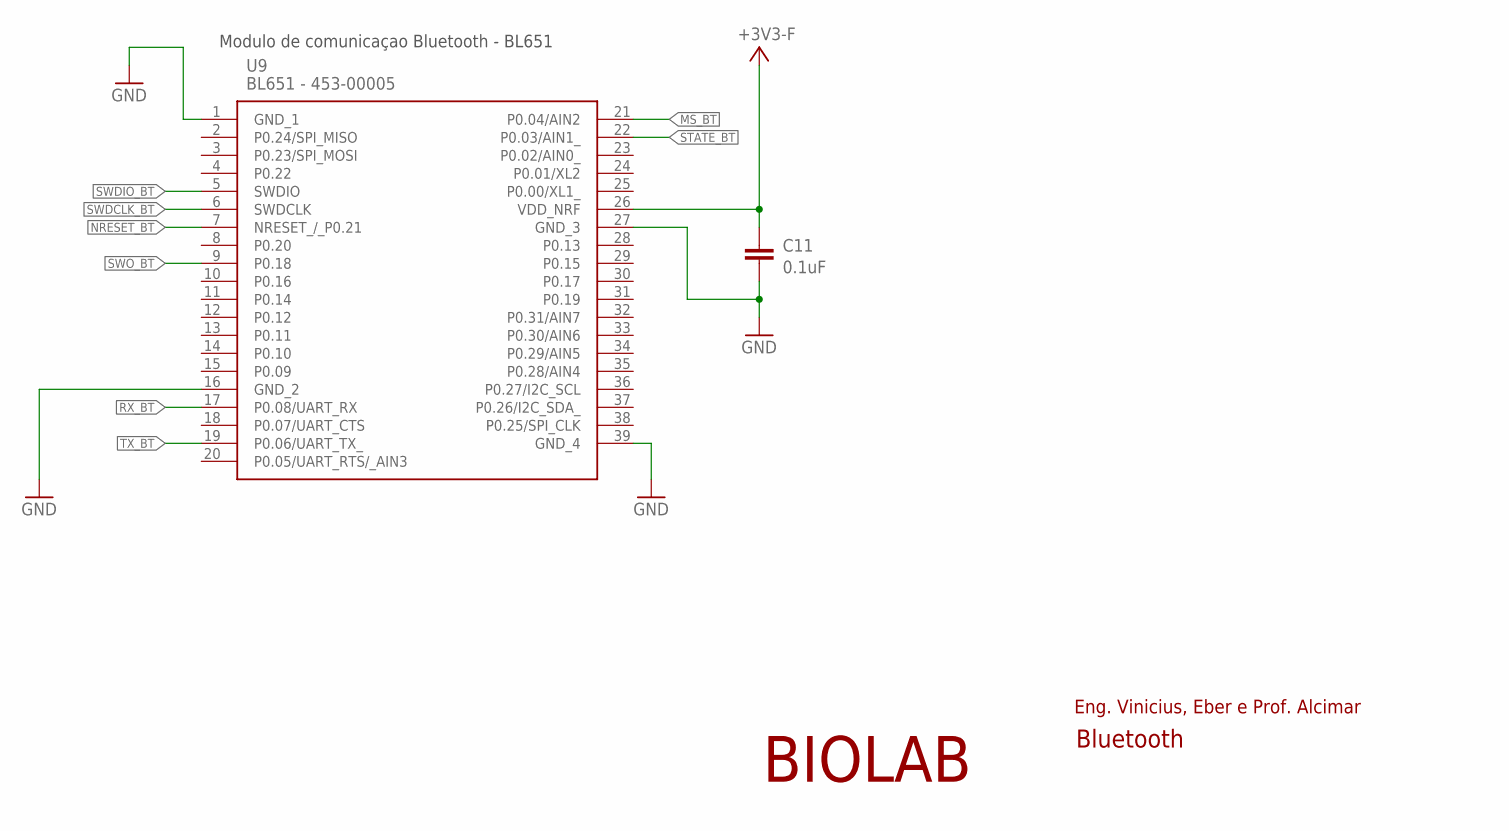
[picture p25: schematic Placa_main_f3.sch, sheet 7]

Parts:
C11: 0.1uF; C0402K
U9: BL651 - 453-00005; 45300005

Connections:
+3V3: C11.2, U9.26 (VDD_NRF); also elsewhere on the board
GND: C11.1, U9.1 (GND_1), U9.16 (GND_2), U9.27 (GND_3), U9.39 (GND_4); also elsewhere on the board
MS_BT: U9.21 (P0.04/AIN2); also elsewhere on the board
NRESET_BT: U9.7 (NRESET_/_P0.21); also elsewhere on the board
RX_BT: U9.17 (P0.08/UART_RX); also elsewhere on the board
STATE_BT: U9.22 (P0.03/AIN1_); also elsewhere on the board
SWDCLK_BT: U9.6 (SWDCLK); also elsewhere on the board
SWDIO_BT: U9.5 (SWDIO); also elsewhere on the board
SWO_BT: U9.9 (P0.18); also elsewhere on the board
TX_BT: U9.19 (P0.06/UART_TX_); also elsewhere on the board

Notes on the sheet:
Modulo de comunicaçao Bluetooth - BL651
BIOLAB
Eng. Vinicius, Eber e Prof. Alcimar
Bluetooth

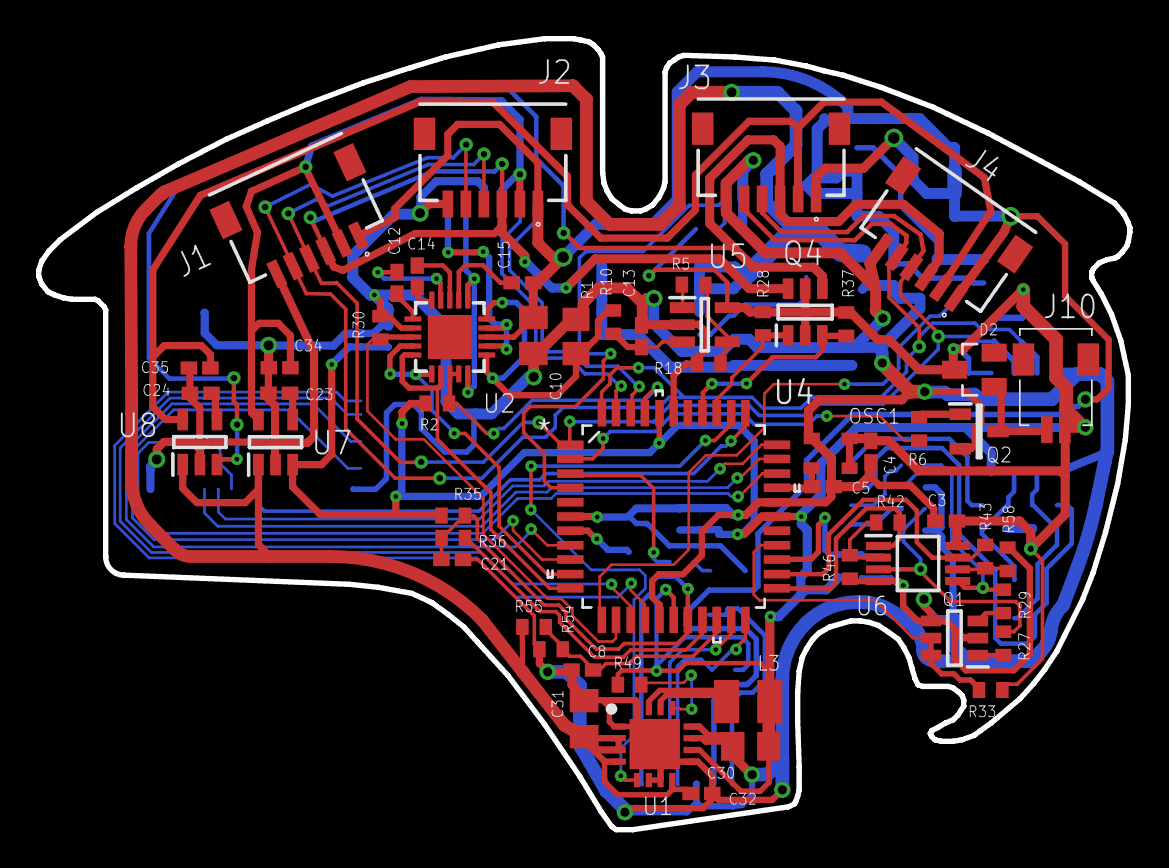
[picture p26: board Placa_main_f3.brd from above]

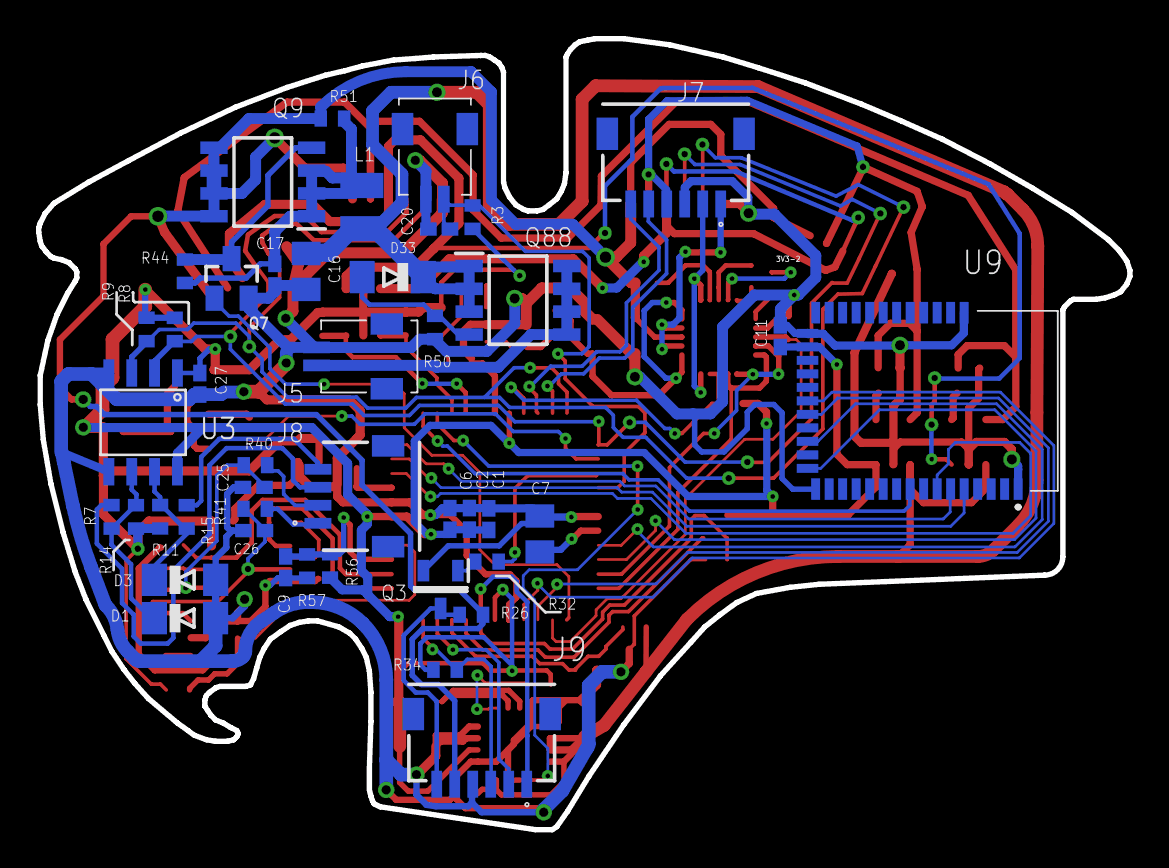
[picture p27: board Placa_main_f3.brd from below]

Board: 2 copper layers, 60.6 x 43.9 mm, 100 parts (44 on the bottom side), 77 nets.

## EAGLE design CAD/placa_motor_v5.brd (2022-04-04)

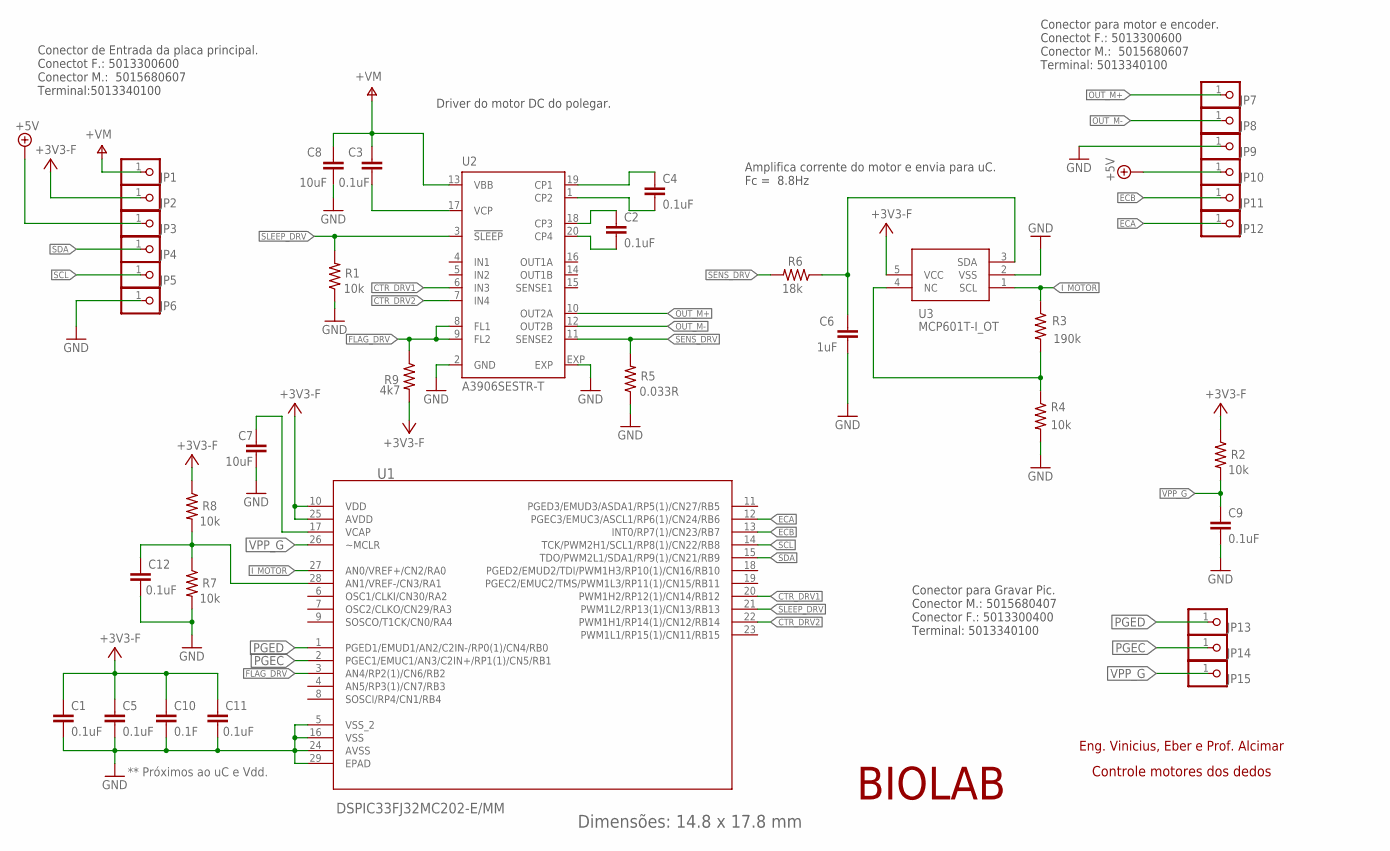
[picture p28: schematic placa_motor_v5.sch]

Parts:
C1, C2, C3, C4, C5, C9, C11, C12: 0.1uF; C0402K
C6: 1uF; C0402K
C7, C8: 10uF; C0805K
C10: 0.1F; C0402K
JP1, JP2, JP3, JP4, JP5, JP6, JP7, JP8, JP9, JP10, JP11, JP12, JP13, JP14, JP15: PINHD-1X1; 1X01
R1, R2, R4, R7, R8: 10k; R0402
R3: 190k; R0402
R5: 0.033R; R0805
R6: 18k; R0402
R9: 4k7; R0402
U1: DSPIC33FJ32MC202-E/MM; QFN65P600X600X100-29N
U2: A3906SESTR-T; QFN20
U3: MCP601T-I_OT; SOT95P270X145-5N

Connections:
+3V3: C1.1, C5.1, C10.1, C11.1, JP2.1, R2.1, R8.1, R9.2, U1.10 (VDD), U1.25 (AVDD), U3.5 (VCC)
+5V: JP3.1, JP10.1
AUX: C12.1, R7.1, R8.2, U1.28 (AN1/VREF-/CN3/RA1)
CTR_DRV1: U1.20 (PWM1H2/RP12(1)/CN14/RB12), U2.6 (IN3)
CTR_DRV2: U1.22 (PWM1H1/RP14(1)/CN12/RB14), U2.7 (IN4)
ECA: JP12.1, U1.12 (PGEC3/EMUC3/ASCL1/RP6(1)/CN24/RB6)
ECB: JP11.1, U1.13 (INT0/RP7(1)/CN23/RB7)
FLAG_DRV: R9.1, U1.3 (AN4/RP2(1)/CN6/RB2), U2.8 (FL1), U2.9 (FL2)
GND: C1.2, C5.2, C6.2, C7.2, C8.1, C9.2, C10.2, C11.2, C12.2, JP6.1, JP9.1, R1.1, R4.2, R5.1, R7.2, U1.5 (VSS_2), U1.16 (VSS), U1.24 (AVSS), U1.29 (EPAD), U2.2 (GND), U2.EXP, U3.2 (VSS)
I_MOTOR: R3.1, U1.27 (AN0/VREF+/CN2/RA0), U3.1 (SCL)
N1: C7.1, U1.17 (VCAP)
N2: R3.2, R4.1, U3.4 (NC)
N3: C6.1, R6.1, U3.3 (SDA)
N4: C4.1, U2.19 (CP1)
N5: C4.2, U2.1 (CP2)
N6: C2.1, U2.18 (CP3)
N7: C2.2, U2.20 (CP4)
N8: C3.2, U2.17 (VCP)
OUT_M+: JP7.1, U2.10 (OUT2A)
OUT_M-: JP8.1, U2.12 (OUT2B)
PGEC: JP14.1, U1.2 (PGEC1/EMUC1/AN3/C2IN+/RP1(1)/CN5/RB1)
PGED: JP13.1, U1.1 (PGED1/EMUD1/AN2/C2IN-/RP0(1)/CN4/RB0)
SCL: JP5.1, U1.14 (TCK/PWM2H1/SCL1/RP8(1)/CN22/RB8)
SDA: JP4.1, U1.15 (TDO/PWM2L1/SDA1/RP9(1)/CN21/RB9)
SENS_DRV: R5.2, R6.2, U2.11 (SENSE2)
SLEEP_DRV: R1.2, U1.21 (PWM1L2/RP13(1)/CN13/RB13), U2.3 (!SLEEP)
V+: C3.1, C8.2, JP1.1, U2.13 (VBB)
VPP_G: C9.1, JP15.1, R2.2, U1.26 (~MCLR)

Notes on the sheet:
Dimensões: 14.8 x 17.8 mm
** Próximos ao uC e Vdd.
Conector para motor e encoder. Conectot F.: 5013300600 Conector M.: 5015680607 Terminal: 5013340100
Conector de Entrada da placa principal. Conectot F.: 5013300600 Conector M.: 5015680607 Terminal:5013340100
BIOLAB
Eng. Vinicius, Eber e Prof. Alcimar
Driver do motor DC do polegar.
Amplifica corrente do motor e envia para uC. Fc = 8.8Hz
Controle motores dos dedos
Conector para Gravar Pic. Conector M.: 5015680407 Conector F.: 5013300400 Terminal: 5013340100

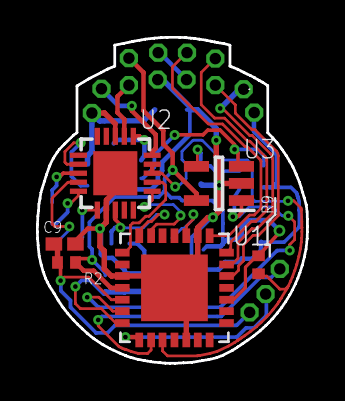
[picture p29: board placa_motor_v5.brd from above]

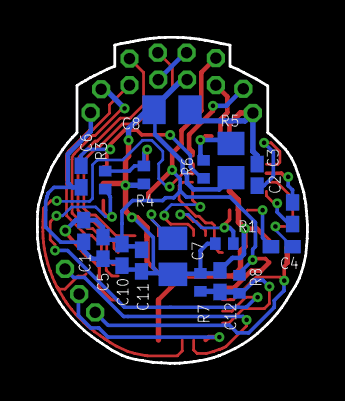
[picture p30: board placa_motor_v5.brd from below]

Board: 2 copper layers, 15.0 x 18.1 mm, 39 parts (18 on the bottom side), 28 nets.

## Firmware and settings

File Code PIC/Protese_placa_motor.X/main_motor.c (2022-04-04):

/*
 * File:   main_motor.c
 * Author: vinic
 *
 * Created on December 13, 2021, 5:12 PM
 * 
 * links:   http://www.mech.tohoku-gakuin.ac.jp/rde/contents/sendai/mechatro/archive/Datasheet05/dsPIC_ADC.pdf
 *          http://www.t-es-t.hu/download/microchip/rm33f28_ADC2_a.pdf
 *          http://ww1.microchip.com/downloads/en/devicedoc/70183d.pdf
 *          https://turbofuture.com/computers/How-to-use-Interrupts-in-Pic-MicroControllers
 *          https://www.pantechsolutions.net/blog/how-to-interface-interrupts-with-dspic30f4011-dspic-development-board/
 */

// DSPIC33FJ32MC202 Configuration Bit Settings

// 'C' source line config statements

// FBS
#pragma config BWRP = WRPROTECT_OFF     // Boot Segment Write Protect (Boot Segment may be written)
#pragma config BSS = NO_FLASH           // Boot Segment Program Flash Code Protection (No Boot program Flash segment)

// FGS
#pragma config GWRP = OFF               // General Code Segment Write Protect (User program memory is not write-protected)
#pragma config GSS = OFF                // General Segment Code Protection (User program memory is not code-protected)

// FOSCSEL
#pragma config FNOSC = FRC              // Oscillator Mode (Internal Fast RC (FRC))
#pragma config IESO = OFF               // Internal External Switch Over Mode (Start-up device with user-selected oscillator source)

// FOSC
#pragma config POSCMD = NONE            // Primary Oscillator Source (Primary Oscillator Disabled)
#pragma config OSCIOFNC = OFF           // OSC2 Pin Function (OSC2 pin has clock out function)
#pragma config IOL1WAY = OFF            // Peripheral Pin Select Configuration (Allow Multiple Re-configurations)
#pragma config FCKSM = CSDCMD           // Clock Switching and Monitor (Both Clock Switching and Fail-Safe Clock Monitor are disabled)

// FWDT
#pragma config WDTPOST = PS32768        // Watchdog Timer Postscaler (1:32,768)
#pragma config WDTPRE = PR128           // WDT Prescaler (1:128)
#pragma config WINDIS = OFF             // Watchdog Timer Window (Watchdog Timer in Non-Window mode)
#pragma config FWDTEN = OFF             // Watchdog Timer Enable (Watchdog timer enabled/disabled by user software)

// FPOR
#pragma config FPWRT = PWR1             // POR Timer Value (Disabled)
#pragma config ALTI2C = OFF             // Alternate I2C  pins (I2C mapped to SDA1/SCL1 pins)
#pragma config LPOL = ON                // Motor Control PWM Low Side Polarity bit (PWM module low side output pins have active-high output polarity)
#pragma config HPOL = ON                // Motor Control PWM High Side Polarity bit (PWM module high side output pins have active-high output polarity)
#pragma config PWMPIN = ON              // Motor Control PWM Module Pin Mode bit (PWM module pins controlled by PORT register at device Reset)

// FICD
#pragma config ICS = PGD1               // Comm Channel Select (Communicate on PGC1/EMUC1 and PGD1/EMUD1)
#pragma config JTAGEN = OFF             // JTAG Port Enable (JTAG is Disabled)

// #pragma config statements should precede project file includes.
// Use project enums instead of #define for ON and OFF.

//#define SYS_FREQ 7370000UL
#define FRC 7370000UL
#define FCY FRC/2
#define _XTAL_FREQ 7370000UL


#include <xc.h>
//#include <p33FJ32GP202.h>
#include <stdio.h>
#include <stdlib.h>
#include <ctype.h>
#include <string.h>
#include <libpic30.h>
//#include <delay.h>;
#include <math.h>
//#include <pps.h>

#define FLAG_DVR    _RB2
#define I_MOTOR     _RA0
#define ECA         _RB6
#define ECB         _RB7
#define CTR_DVR1    _RB12
#define CTR_DVR2    _RB14
#define SLEEP_DVR   _RB13

// Variaveis para encoder
#define MAX_PULSE 500 // Máximo de pulso encoder (valor empírico)
//uint8_t pinALast = 0;
uint16_t pulse = 0;
_Bool limit = 0;

// Variaveis Corrente
#define MAX_CURRENT 4095*0.8 // (80% da corrente máxima medida (valor empírico))

// ----- Funções protótipos----------------------------------------------------/
void Interrupt_Init(void);
void init_ADC(void);
uint16_t readADC(int _ch);
//-----------------------------------------------------------------------------/
int main(void) {
    // OUTPUT
    _TRISB2 = 0x00;
    _TRISB12 = 0x00;
    _TRISB13 = 0x00;
    _TRISB14 = 0x00;

    // INPUT
    _TRISA0 = 0x01;
    _TRISB6 = 0x01;
    _TRISB7 = 0x01;

    // interrupção canais EMG
    // interrupção encoder - OK
    Interrupt_Init();
    // interrupção corrente motor - OK
    // interrupção botão externo
    // I2C
    
    //pinALast = ECB; // posição inicial
    
    // Acionando motor
    SLEEP_DVR = 0x00;
    FLAG_DVR = 0x00;
    CTR_DVR1 = 0x01;
    CTR_DVR2 = 0x00;

    while (1) {
        
        uint16_t _ADC_AN0 = readADC(I_MOTOR); // Leitura AN0
        if ((limit) || (_ADC_AN0 > MAX_CURRENT)) // Passar dos limites para o motor
        {
            SLEEP_DVR = 0x00;
            FLAG_DVR = 0x00;
            CTR_DVR1 = 0x00;
            CTR_DVR2 = 0x00;
        }
        /*
         // TESTE DE OSCILAR PINO PARA GRAVAÇÃO INCIAL
         _RB2 = 0x01;// FLAG_DVR (RB2)
         __delay32(1500000);
         _RB2 = 0x00;//
         __delay32(1500000);
         */
    }
    return 0;
}

void Interrupt_Init(void) {
    _INT0EP = 0; // negative/positive edge detect polarity              - POSITIVE
    _INT0IE = 1; // enable/disable external interrupt                   - ENABLE
    _INT0IP = 1; // 3-bit (0 to 7) interrupt priority config            - 001

}

void __attribute__((interrupt, auto_psv)) _INT0Interrupt(void) {
    if (ECB != ECA) 
    {
        // forward
        limit = 0;
        pulse++;
    } 
    else
    {
        // backward
        limit = 0;
        pulse--;
    }
    if (abs(pulse) == MAX_PULSE) // +/- value MAX_PULSE
    {
            //motor_pwm_config(0, "off");
            limit = 1;
    }
    _INT0IF = 0;
}

void init_ADC(void)
{
    _TRISA0 = 0x01;
    ADPCFG = 0x0000;  //Selecting all analogue pins to analogue mode
    _AD12B = 0x01;
    _CHPS = 0x00;
    AD1CHS0bits.CH0SA = 0;
    
    AD1CHS123bits.CH123SA=0; // Select AN0 for CH1 +ve input
    AD1CON1bits.ADON = 1; // turn on the ADC
    ADPCFGbits.PCFG0 = 0; // AN0 is configured as analog input
}
uint16_t readADC(int _ch)
{                      
    AD1CHS0  = _ch;               // select analog input channel
    ADC1BUF0 = 0x0000; // Reset Buffer
    AD1CON1bits.SAMP = 1;        // start sampling, automatic conversion will follow
    while (!AD1CON1bits.DONE); // wait to complete the conversion
    return ADCBUF0;         // read the conversion result
}

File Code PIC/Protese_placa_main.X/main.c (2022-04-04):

/*
 * File:   main.c
 * Author: vinic
 *
 * Created on December 9, 2021, 1:27 PM
 * 
 * links:
 * https://www.microchip.com/doclisting/TechDoc.aspx?type=CodeExamples
 * https://turbofuture.com/computers/How-Use-ADCs-in-dspic30f-and-dspic33f
 * https://turbofuture.com/computers/Configure-PWM-on-dspic30f-and-dspic33f
 * https://flashgamer.com/blog/comments/basic-blink-example-for-dspic30f4013
 * https://www.youtube.com/watch?v=-Hrz6PZwdiw&list=PLp8IkbtcjNXwearFBxVFtzjGOzzEW1IR_
 * https://ww1.microchip.com/downloads/en/DeviceDoc/50002446C.pdf
 * https://microchipsupport.force.com/s/article/Delay-functions-in-XC16-and-XC8-and-their-functionaility
 * 
 * -----------------------------------------------------------------------------------------------
 * TAREFAS:
 * Testar pinos de controle de alimentação                          - OK
 * Tensão VM                                                        -
 * Tensão +3V3-1                                                    - OK
 * Tensão +3V3-2                                                    - OK
 * Tensão +5V/1                                                     - OK
 * Tensão +5V/1                                                     - OK
 */



// DSPIC33FJ128MC804 Configuration Bit Settings

// 'C' source line config statements


// FBS
#pragma config BWRP = WRPROTECT_OFF     // Boot Segment Write Protect (Boot Segment may be written)
#pragma config BSS = NO_FLASH           // Boot Segment Program Flash Code Protection (No Boot program Flash segment)
#pragma config RBS = NO_RAM             // Boot Segment RAM Protection (No Boot RAM)

// FSS
#pragma config SWRP = WRPROTECT_OFF     // Secure Segment Program Write Protect (Secure segment may be written)
#pragma config SSS = NO_FLASH           // Secure Segment Program Flash Code Protection (No Secure Segment)
#pragma config RSS = NO_RAM             // Secure Segment Data RAM Protection (No Secure RAM)

// FGS
#pragma config GWRP = OFF               // General Code Segment Write Protect (User program memory is not write-protected)
#pragma config GSS = OFF                // General Segment Code Protection (User program memory is not code-protected)

// FOSCSEL
#pragma config FNOSC = FRC              // Oscillator Mode (Internal Fast RC (FRC))
#pragma config IESO = OFF               // Internal External Switch Over Mode (Start-up device with user-selected oscillator source)

// FOSC
#pragma config POSCMD = NONE            // Primary Oscillator Source (Primary Oscillator Disabled)
#pragma config OSCIOFNC = OFF           // OSC2 Pin Function (OSC2 pin has clock out function)
#pragma config IOL1WAY = OFF            // Peripheral Pin Select Configuration (Allow Multiple Re-configurations)
#pragma config FCKSM = CSECMD           // Clock Switching and Monitor (Clock switching is enabled, Fail-Safe Clock Monitor is disabled)

// FWDT
#pragma config WDTPOST = PS32768        // Watchdog Timer Postscaler (1:32,768)
#pragma config WDTPRE = PR128           // WDT Prescaler (1:128)
#pragma config WINDIS = ON              // Watchdog Timer Window (Watchdog Timer in Window mode)
#pragma config FWDTEN = OFF             // Watchdog Timer Enable (Watchdog timer enabled/disabled by user software)

// FPOR
#pragma config FPWRT = PWR1             // POR Timer Value (Disabled)
#pragma config ALTI2C = ON              // Alternate I2C  pins (I2C mapped to ASDA1/ASCL1 pins)
#pragma config LPOL = ON                // Motor Control PWM Low Side Polarity bit (PWM module low side output pins have active-high output polarity)
#pragma config HPOL = ON                // Motor Control PWM High Side Polarity bit (PWM module high side output pins have active-high output polarity)
#pragma config PWMPIN = ON              // Motor Control PWM Module Pin Mode bit (PWM module pins controlled by PORT register at device Reset)

// FICD
#pragma config ICS = PGD1               // Comm Channel Select (Communicate on PGC1/EMUC1 and PGD1/EMUD1)
#pragma config JTAGEN = OFF             // JTAG Port Enable (JTAG is Disabled)

// #pragma config statements should precede project file includes.
// Use project enums instead of #define for ON and OFF.

/*
// Internal FRC Oscillator
_FOSCSEL(FNOSC_FRC); // FRC Oscillator 
_FOSC(FCKSM_CSECMD & OSCIOFNC_OFF & POSCMD_XT);
// Clock Switching is enabled and Fail Safe Clock Monitor is disabled
// OSC2 Pin Function: OSC2 is Clock Output
// Primary Oscillator Mode: Disabled

_FWDT(FWDTEN_OFF); // Watchdog Timer Enabled/disabled by user software
// (LPRC can be disabled by clearing SWDTEN bit in RCON register
_FPOR(FPWRT_PWR1); // Turn off the power-up timers.
_FGS(GCP_OFF); // Disable Code Protection
 */
//#define SYS_FREQ 7370000UL
#define FRC 7370000UL
#define FCY FRC/2
//#define _XTAL_FREQ 7370000UL


#include <xc.h>
#include <stdio.h>
#include <stdlib.h>
#include <ctype.h>
#include <string.h>
#include <libpic30.h>
//#include <delay.h>;
#include <math.h>
//#include <pps.h>


int main(void) {

    // EXAMPLE!!!
    // Configure Oscillator to operate the device at 40Mhz
    // Fosc= Fin*M/(N1*N2), Fcy=Fosc/2
    // Fosc= 8M*40/(2*2)=80Mhz for 8M input clock
    PLLFBD = 5; // M=40
    CLKDIVbits.PLLPOST = 0; // N1=2
    CLKDIVbits.PLLPRE = 0; // N2=2
    OSCTUN = 0; // Tune FRC oscillator, if FRC is used


    // Disable Watch Dog Timer
    RCONbits.SWDTEN = 0;

    // Make all the ANx pins as digital pins
    AD1PCFGL = 0xFFFF;
    //AD1PCFGH = 0xFFFF;

    // -------------------------------------------------------------------------
    /*
    //AD1PCFG = 0xFFFF; // set to digital I/O (not analog)
    TRISA = 0x1F; // REset
    PORTA = 0x00;
    LATA = 0x00;
    ODCA = 0x00;
    
    TRISC = 0x1F;
    PORTC = 0x00;
    LATC = 0x00;
    ODCC = 0x00;
    */
    //TRISA = 0x00;
    _TRISA10 = 0x00;
    _TRISA9 = 0x00;
    _TRISB5 = 0x00;
    TRISC = 0x00;
    //_TRISC4 = 0x00;

    while (1) {
        
        //PORTA = 0b10010000000;
        _RA10 = 0x01; //0b1; // FLAG_VM
        _RA9 = 0x01; //0b1; // SYNC_REG
        PORTC = 0x18; //0b11000; //FLAG_V1 (RC3) E FLAG_V2 (RC4)
        // SLEEP_DVR (RA7)
        _RB5 = 0x01;// FLAG_DVR (RB5)
        // SYNC_REG (RA9) (LOW =  ECONOMIA DE ENERGIA, HIGH = transfere a energia não utilizada de volta para a entrada)
        
       // __delay32(1500000);
        __delay_ms(500);
        
        //_RA10 = 0x00; //0b0;
        //PORTA = 0b00000000000;
        _RB5 = 0x00;// FLAG_DVR (RB5)
        PORTC = 0x00; //0b00000;
        __delay_ms(500);
 
    }

    return 0;
}
